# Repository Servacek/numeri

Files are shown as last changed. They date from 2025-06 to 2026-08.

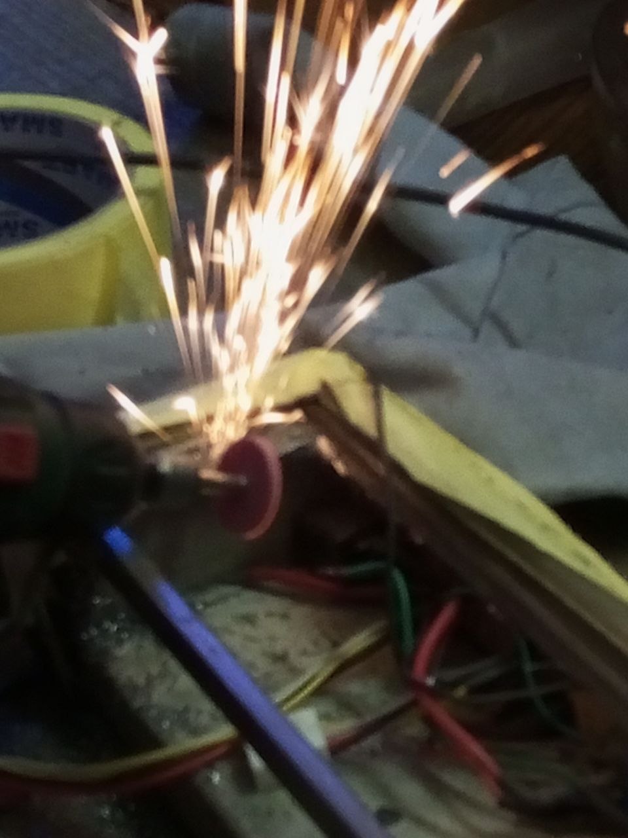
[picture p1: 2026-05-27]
docs/pictures/dokumentacne_foto/photo_2026-05-26_11-01-02.jpg

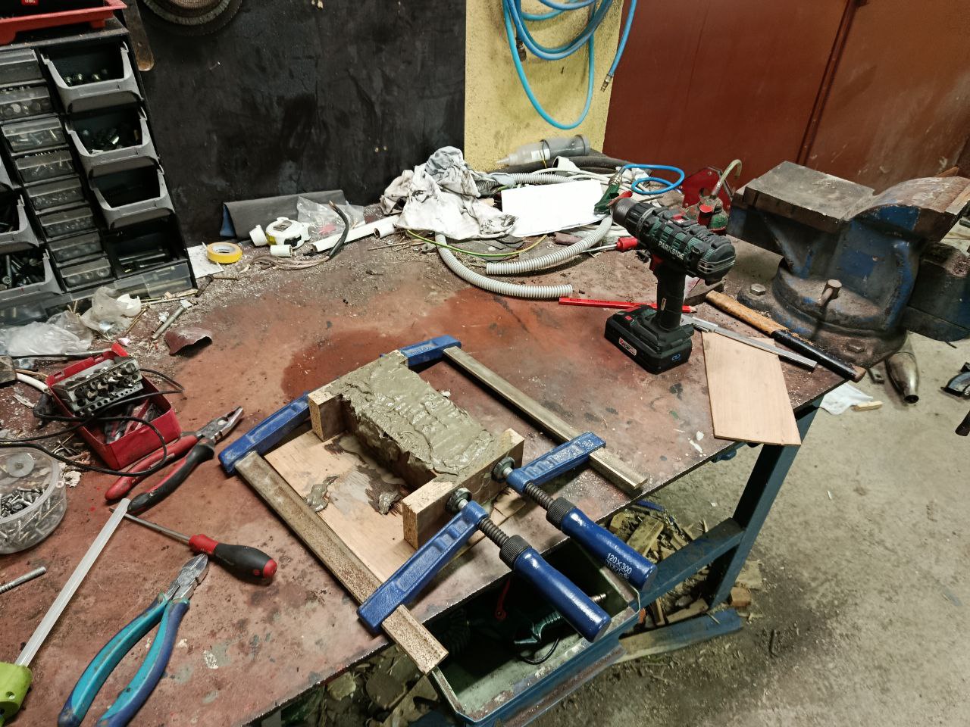
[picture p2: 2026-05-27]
docs/pictures/dokumentacne_foto/photo_2026-05-26_11-04-23.jpg

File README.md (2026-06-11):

# Numitronové Hodiny - Numeri

Digitálne hodiny využívajúce na zobrazovanie času staré sovietske numitrony IV-9. Podporujú tiež pripojenie rádiového modulu DCF77 pre automatické nastavovanie času podľa atomových hodín z Mainflingenu.

https://github.com/user-attachments/assets/5947127a-6d7e-4e79-9d8d-92cfa04d009d

## DCF77 Anténa



Vlastná 140 mm anténa sa zdá byť najefektívnejšie a cenovo najdostupnejšie riešenie. Čim väčšia feritová tyč, tým lepšie.

## Schéma zapojeniaa návrh plošného spoja




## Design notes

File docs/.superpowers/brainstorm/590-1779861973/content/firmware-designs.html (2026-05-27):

# Superpowers Brainstorming

Connected

Three design directions for the firmware features section. Click the one you like best.

Option A — Description list

Description List Clean · technical · readable

Firmvér pre Numeri hodiny beží na mikrokontroléri ATmega328P (16 MHz). Napísaný v C++ s inline AVR asemblerom — bez operačného systému, bez dynamickej alokácie.

DS3231 RTC Presný čas s teplotne kompenzovaným oscilátorom, uchovaný aj po výpadku napájania.

DCF77 sync Automatická synchronizácia s európskym rádiovým časovým signálom.

Auto-jas & noc LDR senzor pre stmievanie; konfigurovateľný nočný režim vypne displej.

Časovače Až 4 hodinové udalosti — nočný režim, DCF sync alebo zmena jasu.

Crossfade Plynulé ISR-riadené prechody číslic pri každej zmene hodnoty.

Teplota & log Zobrazenie teploty z AVR senzora; sériový debug monitor.

↓ Stiahnuť firmvér

⬡ Celý repozitár

Ako skompilovať a nahrať

Option B — Inline table

Compact Table Dense · scannable · data-forward

Firmvér pre Numeri hodiny beží na mikrokontroléri ATmega328P (16 MHz). Napísaný v C++ s inline AVR asemblerom — bez operačného systému, bez dynamickej alokácie.

DS3231 RTC | Presný čas s TXCO, uchovaný po výpadku napájania.
DCF77 | Automatická synchronizácia s rádiovým časovým signálom.
Auto-jas / noc | LDR pre automatické stmievanie; nočný režim vypne displej.
Časovače ×4 | Hodinové udalosti — nočný režim, DCF sync, zmena jasu.
Crossfade | ISR-riadené PWM prechody číslic.
Teplota / log | AVR teplomer; sériový monitor s úrovňami logu.

↓ Stiahnuť firmvér

⬡ Celý repozitár

Ako skompilovať a nahrať

Option C — Tags only, no descriptions

Feature chips Minimal · action-first

Firmvér pre Numeri hodiny beží na mikrokontroléri ATmega328P (16 MHz). Napísaný v C++ s inline AVR asemblerom — bez operačného systému, bez dynamickej alokácie. Podporuje DS3231 RTC, DCF77 synchronizáciu, automatický jas, nočný režim, crossfade animácie a sériový monitor.

DS3231 RTC DCF77 Auto-jas Nočný režim Crossfade Teplomer Serial monitor

↓ Stiahnuť firmvér

⬡ Celý repozitár

Ako skompilovať a nahrať

Click a design to select it, then let me know in the terminal

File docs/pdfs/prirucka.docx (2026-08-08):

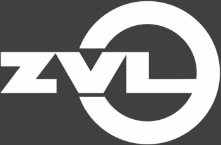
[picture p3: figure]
Úvod - ZVL SLOVAKIA

NUMERI 50

Digitálne hodiny

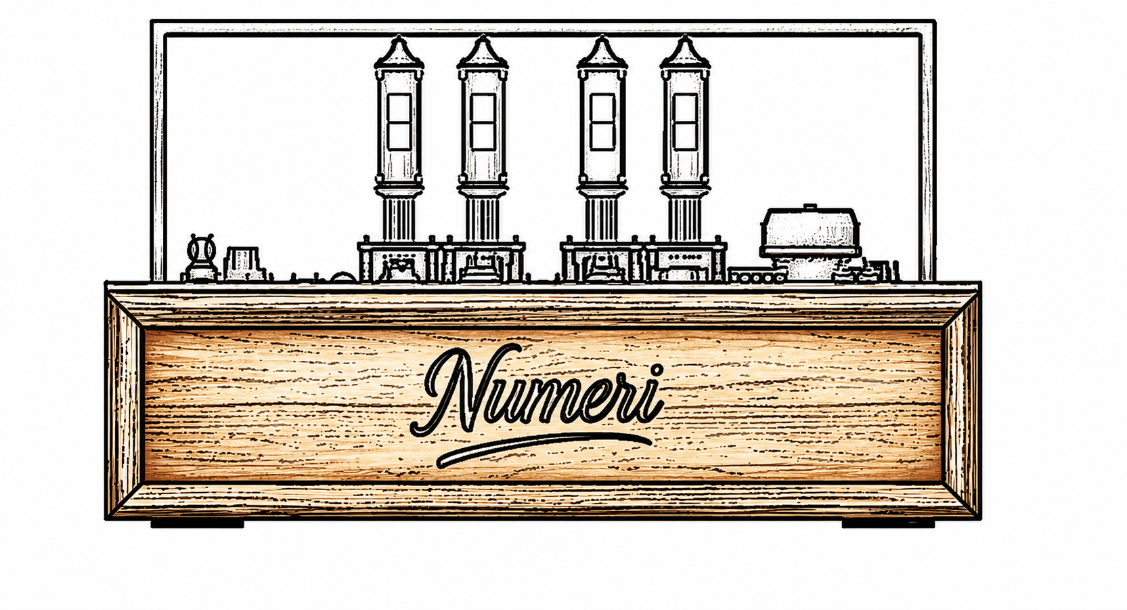
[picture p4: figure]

Návod na obsluhu

Obsah

# Digitálne hodiny Numeri 50

## Úvod

Numeri 50 sú rádiovo nastaviteľné digitálne hodiny, ktoré na zobrazovanie času používajú sovietske numitrony IV-9.

## História numitronov IV-9

V druhej polovici 60. a začiatkom 70. rokov potrebovala sovietska prístrojová a špeciálna technika kontrastný, odolný a jednoducho ovládateľný číslicový displej. LED-ky sa zatiaľ len vyvíjali a boli príliš drahé na praktické použitie.

Oproti známym a rozšíreným digitronom, v ktorých svietil dútnavý výboj v neónovej banke so studenou katódou, numitrony fungovali v podstate na princípe klasickej žiarovky. Išlo teda o akúsi 7-segmentovku, kde jednotlivé segmenty boli tvorené nízkopríkonovými wolfrámovými vláknami. Ich zapojenie bolo teda veľmi jednoduché a vyžadovalo len malé napätie, ktoré zvládali aj vtedajšie polovodiče.

IV-9 sa montoval vo viacerých lampových závodoch v rámci rozsiahlej sovietskej siete elektrovákuových podnikov. V praxi sa IV-9 objavoval v hodinách, kalkulačkách, meradlách a v špeciálnej aparatúre.

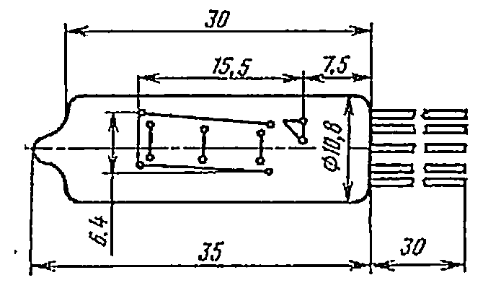
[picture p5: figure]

Obr. 1 Kótovaný technický nákres numitronu IV-9 z pôvodných sovietskych dokumentov.

Technické údaje o použitých numitronoch IV-9:
Model: IV-9 (ИВ-9)
Rok výroby: 1984
Menovité napätie: 3,15 V
Menovitý prúd: ~20–22 mA na segment
Jas: ≥ 2000 cd/m²
Životnosť: minimálne 10 000 hodín

## Ovládací panel

1 | Tlačidlo zmeny hodnoty na pozícii kurzora. ()
2 | Vypínač hodín (hore zapnuté, dole vypnuté).
3 | Napájací USB-C konektor (vstup 5 V a aspoň 1 A).
4 | Konektor na pripájanie DCF77 prijímača (typ GX-12).
5 | Indikačná RGB luminiscenčná dióda (LED).
6 | Tlačidlo posunu kurzora. ()

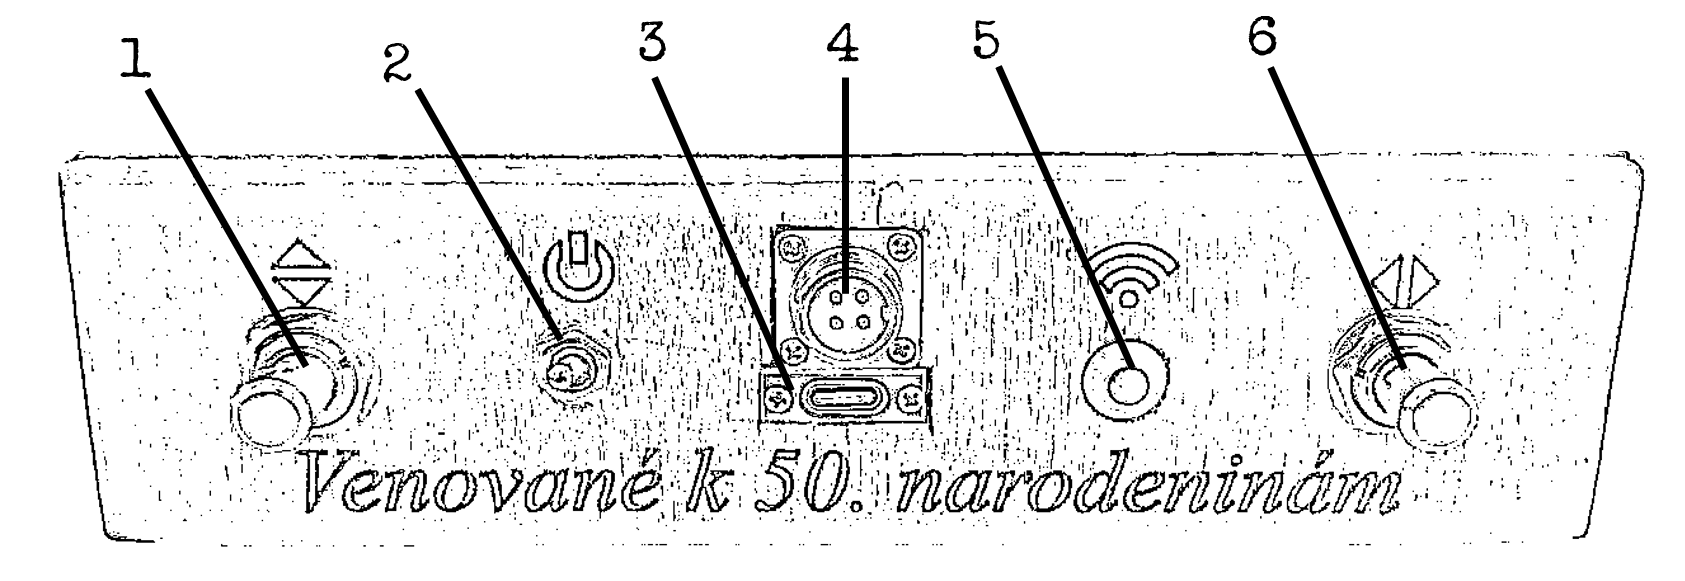
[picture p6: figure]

Obr. 2. Ovládací panel hodín na zadnej strane podstavca.

## Nastavovanie hodín

Na krajoch ovládacieho panela sa nachádzajú dve tlačidlá označené ikonkami a , ktoré umožňujú nastavovanie hodín. Pre vstup do nastavovacieho režimu držte obe tlačidlá stlačené dovtedy, kým sa nezobrazí kurzor (malá šípka vpravo dole na jednom z numitronov, viď Obr. 3). Ukončenie nastavovacieho režimu funguje rovnako — dlhým stlačením oboch tlačidiel, kým kurzor úplne nezmizne.

V nastavovacom režime každý numitron zodpovedá jednému konkrétnemu nastaveniu. Číslo zobrazené na danom numitrone určuje aktuálnu hodnotu tohto nastavenia. Pomocou tlačidla sa presúva kurzor medzi jednotlivými numitronmi a tlačidlom sa mení hodnota vybraného nastavenia.

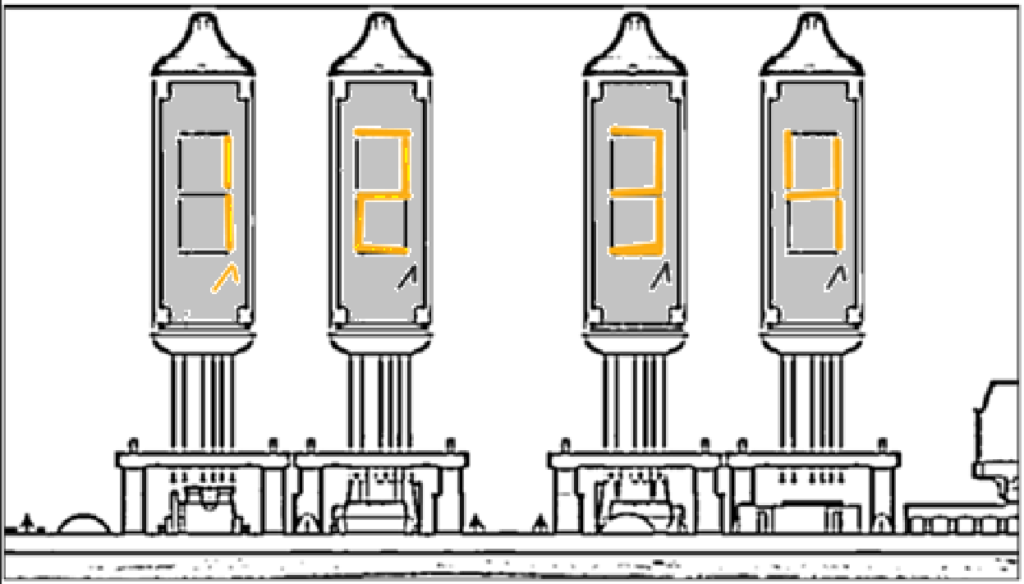
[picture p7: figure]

Obr. 3 Detailný pohľad na numitronový displej v nastavovacom režime (viditeľný kurzor na prvom numitrone). Každý z numitronov displeja zobrazuje svoje poradové číslo pre demonštračné účely.

Kurzor

## Stránky nastavení

Keďže počet nastavení je pomerne veľký, numitronový displej ich nedokáže zobraziť všetky naraz, preto sú rozdelené do tzv. stránok nastavení.

Stránka je jednoducho štvorica nastavení zobrazená naraz (každé nastavenie zobrazuje jeden numitron). Pre každú zo stránok sa nižšie nachádza tabuľka ktorá danú stránku a jej nastavenia popisuje týmito tromi stĺpcami:

1. prvý stĺpec obsahuje poradové čísla numitronov (číslované spredu zľava, viď Obr. 3),
2. druhý stĺpec uvádza rozsah hodnôt, ktoré dané nastavenie môže nadobudnúť, pričom hodnota v zátvorke predstavuje predvolenú hodnotu,
3. tretí stĺpec poskytuje stručný popis príslušného nastavenia a jeho možných hodnôt.

Medzi stránkami je možné prechádzať krátkym stlačením oboch krajných tlačidiel. Pri prechode na novú stránku sa zmeny vykonané na predchádzajúcej stránke uložia.

Poradové číslo numitronu | Rozsah hodnôt | Stručný popis nastavenia prípadne jeho možných hodnôt.

STRANA 1 – Nastavenia času
1. | (0)-2 | Cifra desiatok hodín.
2. | (0)-9 | Cifra jednotiek hodín.
3. | (0)-5 | Cifra desiatok minút.
4. | (0)-9 | Cifra jednotiek minút.

STRANA 2 – Všeobecné nastavenia
1. | 0, (1) | 0 – Manuálny jas, 1 – Automatický jas,
2. | 0-8 (5) | Úroveň jasu indikačnej LED: 0 – vypnutá, 8 – maximálny jas,
3. | (0), 1 | Prúdový senzor displeja: 0 – vypnutý (bez softvérovej ochrany) 1 – zapnutý (ochrana pred nadprúdom a podprúdom) Poznámka: Predvolene vypnutý pre prípad vážnej chyby senzora. Výrobné nastavenia je vždy možné obnoviť dlhým stlačením tlačidla RESET (viď strana 12).
4. | 0, (1) | Vypínanie prijímača DCF77: 0 – DCF77 prijímač vypnutý, 1 – DCF77 prijímač zapnutý,

STRANA 3 – Časovače
1. | (0)-4 | Identifikačné číslo (ID) časovača.
2. | (0)-3 | Akcia časovača. 0 – žiadna akcia, 1 – zapnutie nočného režimu (viď strana 13), 2 – vypnutie nočného režimu, 3 – vykonanie 60 minútového pokusu o synchronizáciu času pomocou DCF77 prijímača (viď strana 15),
3. | (0)-2 | Cifra desiatok hodín časovača.
4. | (0)-9 | Cifra jednotiek hodín časovača.

Poznámka: časovače slúžia na automatické spúšťanie určitých akcií (viď zoznam vyššie) v nastavenom čase. Ak je viac časovačov nastavených na rovnakú hodinu, spustia sa podľa poradia ich identifikačných čísel (ID) (t. j. časovač s najmenším číslom prvý, po ňom časovač s druhým najmenším číslom atď...).

Číslo numitronu | Rozsah hodnôt | Stručný popis nastavenia

STRANA 4 – Dátum
1. | (0)-3 | Cifry aktuálneho dňa, napr. 20.
2. | 0-9 (1)
3. | (0)-1 | Cifry aktuálneho mesiaca, napr. 12.
4. | 0-9 (1)

STRANA 5 – Rok
1. | (O)-9 | Cifry aktuálneho roku po poradí. Hodiny tento údaj používajú na určovanie priestupných rokov.
2. | (0)-9
3. | (O)-9
4. | (O)-9

Poznámka: Hodnota v zátvorke je predvolená (výrobné nastavenie).

Pre ukončenie nastavovacieho režimu držte stlačené obe krajné tlačidlá až kým nezmizne kurzor. Prípadne sa nastavovací režim vypne automaticky po piatich minútach neaktivity a to bez uloženia zmien na poslednej upravovanej stránke nastavení.

## Nastavovanie jasu displeja

Mimo nastavovacieho režimu slúžia krajné tlačidlá aj na nastavovanie jasu numitronového displeja. Táto funkcia je dostupná len vtedy, keď je v nastaveniach hodín vypnuté automatické riadenie jasu.

— zvýši jas displeja o jednu úroveň
— zníži jas displeja o jednu úroveň

## Zobrazovanie dátumu a teploty

Krátkym stlačením oboch tlačidiel sa zobrazí teplota okolia, ďalším stlačením dátum — oba údaje len na pár sekúnd, po ktorých sa hodiny vrátia k zobrazeniu času.

## Základné komponenty hodín

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
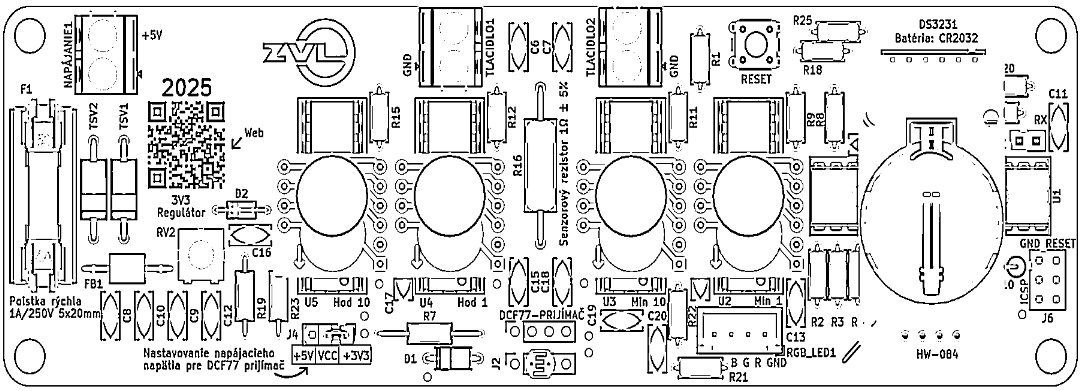
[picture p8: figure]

Obr. 4 Pohľad zhora na dosku plošného spoja a jej komponenty.

## 1. Poistka

Ide o hardvérovú ochranu pred nadprúdom. Poistka je dimenzovaná tak, aby sa vypálila len pri závažnej chybe v elektronike hodín. Teda pri vypálení, odporúčame problém riešiť servisne (viď strana 18).

## 2. Napájanie

Hodiny sa napájajú zo zdroja s výstupom 5 V schopným dlhodobého dodávania výkonu o veľkosti aspoň 5 W.

## 3. QR-kód s odkazom na web

Na doske plošného spoja sa zhora z pohľadovej časti nachádza QR-kód, ktorý obsahuje odkaz na stránku hodín, na ktorej nájdete elektronickú podobu tohto návodu na obsluhu, 3D model a schému hodín, fotografie z procesu návrhu a výroby ako aj kompletný stiahnuteľný firmvér. Odkaz stránky: https://servacek.github.io/numeri/

## 4. Trimmer nastavujúci úroveň napätia DCF77 prijímača

Doska hodín disponuje vlastným napäťovým regulátorom so Zenerovou diódou, ktorý vytvára nastaviteľné napätie (1,1 – 3,6 V) pre DCF77 prijímač — rôzne typy prijímačov totiž vyžadujú rôzne napájacie napätie.

Výstupné napätie regulátora sa nastavuje pomocou trimmera. S trimmerom manipulujte len v nevyhnutných prípadoch (napr. pri výmene prijímača) — nesprávne nastavenie môže viesť k trvalému poškodeniu prijímača.

## 5. Prepojka nastavujúca napäťový zdroj DCF77 prijímača

V prípade potreby sa dá regulátor (4) prepojkou obísť úplne a napájať prijímač priamo zo zdroja hodín (5 V). Pozor — priame napájanie môže poškodiť prijímač s nižším napájacím napätím ako 5 V.

## 6. Svetelný senzor pre automatické prispôsobenie jasu

Hodiny si dokážu regulovať jas displeja na základe okolitého svetla (napr. cez deň je žiaduce, aby displej svietil silnejšie ako v noci). Pri zapnutom automatickom jase nejde nastavovať jas manuálne. Túto funkciu je možné vypnúť v nastaveniach (viď strana 8).

## 7. Senzor prúdového odberu displeja

V rámci ochrany hodín aj numitronov používame priemyselný prúdový senzor s presnosťou 0,5%. Tento senzor umožňuje mikrokontroléru rozpoznať chyby displeja, napríklad vypálené vlákno alebo skrat, a potom displej hodín bezpečne vypnúť.

## 8. Tlačidlo RESET

Krátkym stlačením tlačidla sa hodiny reštartujú. Ak tlačidlo podržíte počas celého spúšťania zariadenia (indikovaného žltou farbou indikačnej LED, viď stranu 16), obnovia sa výrobné nastavenia.

## 9. Mikrokontrolér

Hodiny sú riadené čipom ATmega328 s predinštalovaným firmvérom, ktorý je možné v prípade potreby preinštalovať pomocou ICSP zbernice osadenej na doske hodín.

Súčasťou čipu je aj 1 kB EEPROM pamäť, ktorá uchováva nastavenia aj po odpojení hodín z elektrickej siete. Životnosť každej z jej pamäťových buniek je 100 000 zápisov. Ak sa nastavenia neukladajú, jedinou opravou je výmena celého čipu ATmega328 a opätovné napálenie firmvéru dostupného na stránke hodín.

## 10. Záložná batéria

Zaisťuje zachovanie času aj pri odpojení hodín z elektrickej siete. Pri bežných podmienkach by mala vydržať približne 5 rokov. Ak si hodiny nezachovávajú správny čas po vypojení zo siete, batériu je treba vymeniť za mincovú batériu CR2032 podobnej kvality.

## 11. UART zbernica

Používa sa pri ladení firmvéru hodín, pretože umožňuje odosielať stavové výpisy (logy) z hodín do počítača.

## 12. ICSP zbernica

Umožňuje nahrávanie firmvéru do mikrokontroléra hodín pomocou špeciálnych USB zariadení (tzv. ICSP programátorov). Pri použití vhodného softvéru je možné na programovanie využiť aj vývojovú dosku Arduino. Ak chcete dosku hodín napájať priamo z ICSP zbernice, je potrebné najprv prepnúť vypínač hodín (viď obr. 2) do vypnutej polohy, aby sa predišlo súbehu viacerých zdrojov napájania.

## Nočný režim

Režim, v ktorom je displej vypnutý, zatiaľ čo hodiny zostávajú zapnuté. Stlačením ľubovoľného tlačidla panelu sa displej na niekoľko sekúnd opäť zapne. Pri vstupe do nastavení hodín sa nočný režim vypne úplne.

## Úložný priestor

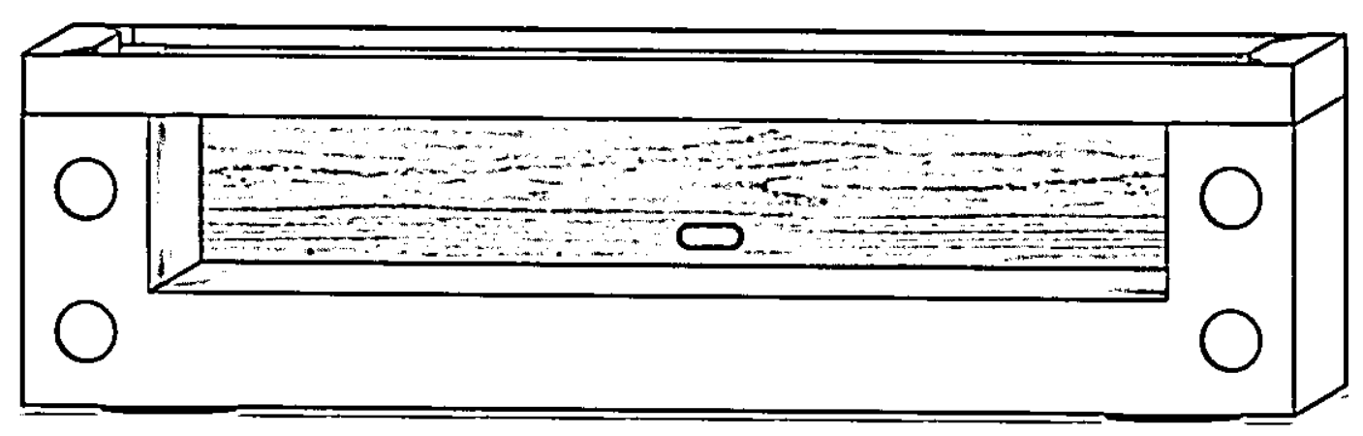
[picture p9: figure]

Obr. 5 Podstavec hodín s odkrytým predným krytom, uchyteným magnetmi, ktorý odhaľuje úložný priestor.

Súčasťou podstavca hodín je aj úložný priestor na náhradné diely a nástroje na základný servis.

Obsahuje:

- náhradný numitron osadený na pätici
- náhradnú mincovú batériu CR2032
- schému zapojenia hodín vo formáte A2

# Prijímač DCF77

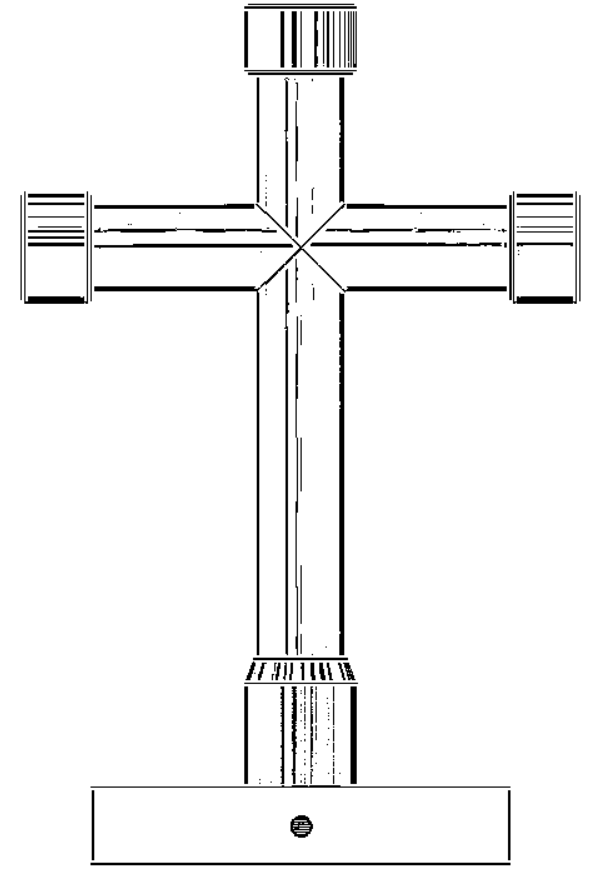
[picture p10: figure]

Obr. 6 Prijímač rádiového signálu DCF77 na podstavci

K hodinám sa dodáva aj rádiový prijímač v tvare kríža, v ktorom je umiestnená 140-milimetrová feritová anténa vlastnej výroby, odladená tak, aby rezonovala pri frekvencii 77,5 kHz na ktorej vysielajú atómové hodiny z Mainflingenu (Nemecko) svoj časový signál. Tento signál používajú hodiny k automatickému nastaveniu času a prechodu zo zimného času na letný a naopak.

## Orientácia prijímača

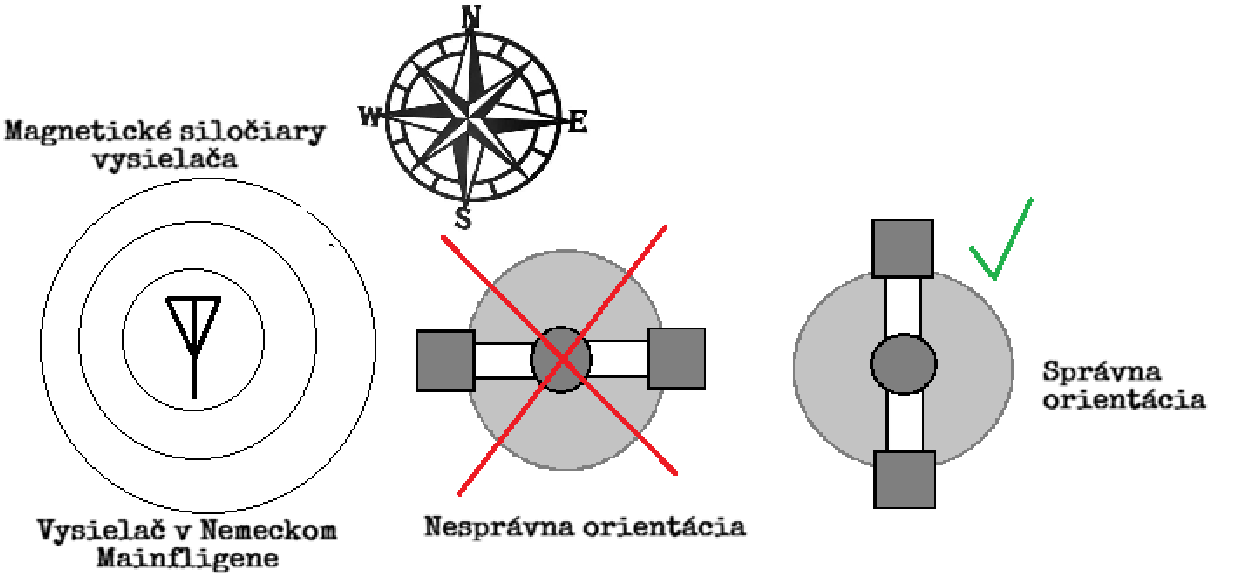
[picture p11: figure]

Obr. 7 Správna a nesprávna orientácia prijímača voči vysielaču.

Keďže feritové antény sú z povahy závislé od orientácie, odporúčame prijímač otočiť tak, aby ramená jeho kríža smerovali na sever a juh (ako je vidieť na Obr. 7). Ak je orientácia správna a signál dostatočne kvalitný, indikačná LED by mala blikať v pravidelných sekundových intervaloch oranžovou farbou.

## Automatické nastavenie hodín

Hodiny sa pokúsia o synchronizáciu ihneď po zapnutí alebo v čase nastavenom v časovači. Ak sa synchronizácia nepodarí do 60 minút, pokusy sa ukončia a obnovia sa až pri ďalšom podnete.

## Stavy indikačnej LED

Indikačná RGB LED na zadnom paneli slúži na informovanie používateľa o stave hodín bez narušenia zobrazenia času na numitronovom displeji. Rôzne farby a režimy blikania signalizujú konkrétne stavy zariadenia.

Stav indikačnej LED | Význam
Oranžové bliknutie raz za sekundu | Synchronizácia času práve prebieha a signál je kvalitný.
Chaotické oranžové blikanie | Synchronizácia času práve prebieha ale signál je nekvalitný alebo zarušený.
Stála žltá farba | Hodiny sú v procese načítavania a inicializácie a nie je možné ešte s nimi interagovať.
Stála zelená farba | Čas bol naposledy úspešne synchronizovaný.
Stála červená farba | Posledný pokus o synchronizovanie času bol neúspešný.
Stála modrá farba | Nahrávanie nového programu do mikrokontroléra hodín.
Intenzívne pravidelné blikanie červenou farbou | Prúdový senzor displeja zaznamenal nadprúd (napr. skrat).
Intenzívne pravidelné blikanie modrou farbou | Prúdový senzor displeja zaznamenal podprúd (napr. vypálený alebo zle pripevnený numitron).
Trojité bliknutie bielou farbou | Hodiny boli obnovené na výrobné (predvolené) nastavenia pomocou dlhého stlačenia tlačidla RESET (viď Obr. 4).

V prípade potreby je možné v nastaveniach hodín upraviť jas tejto indikačnej LED, aby bola menej rušivá, prípadne ju kompletne vypnúť (nastavením jasu na 0), viď strana 8.

## Numitronový displej a jeho životnosť

Numitrony displeja sú pri prevádzke napájané regulovaným spínaným napätím s maximálnou efektívnou hodnotou (dosiahnutou pri maximálnom jase) pohybujúcou sa okolo 1,5 V až 2 V.

Ide o napätie, ktoré je výrazne nižšie ako maximálne dovolené napätie uvádzané v oficiálnych dokumentoch (4,5 V) ako aj nominálne napätie (3,15 V), pričom displej stále ostáva dobre čitateľný.

Štúdie ukazujú, že životnosť volfrámových vlákien rastie exponenciálne so znižujúcim sa napätím, zatiaľ čo jas klesá len lineárne (viď obr. 8). Vďaka prevádzke pri zníženom napätí je možné predĺžiť životnosť displeja z pôvodných približne 10 000 hodín až na viac ako 500 000 hodín. Zmeny napätia vlákien sú realizované plynule, aby sa predišlo nadprúdom pri zapnutí, ktoré vznikajú v dôsledku nízkeho odporu studených vlákien.

Pre dosiahnutie čo najdlhšej životnosti numitronov odporúčame nastaviť čo najnižší jas a použiť dva časovače – jeden na večerné vypnutie displeja a druhý na jeho zapnutie nad ránom (viď strana 8).

Zmeny v %

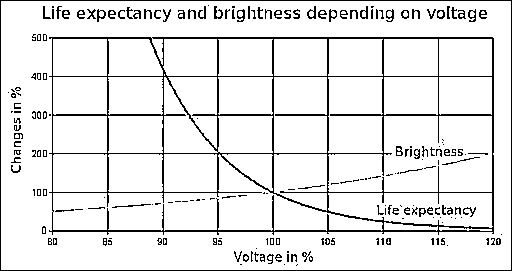
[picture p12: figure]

Obr. 8 Závislosť životnosti vlákien na napájacom napätí

Jasnosť

% z nominálného napätia

Životnosť

## Riešenie problémov

Problém | Riešenie
Hodiny si neudržujú správny čas po vypnutí. | Mincová batéria (Obr. 4) je vybitá.
Hodiny sa oneskorujú alebo nefunguje automatická synchronizácia času. | Uistite sa, že orientácia prijímača je správna (Obr. 7) a prijímač je pevne pripojený. Následne hodiny reštartujte pre zahájenie opätovnej synchronizácie. Indikačná LED by mala počas synchronizácie blikať v pravidelných sekundových intervaloch oranžovou.
Niektoré vlákna nesvietia. | Reštartujte hodiny. Pri štarte by sa mali rozsvietiť všetky vlákna na všetkých numitronoch. Numitrony, u ktorých sa nerozsvietili všetky vlákna je potrebné vymeniť za nové. Kontaktujte servis.
Hodiny sa nedajú zapnúť. | Uistite sa, že hodiny sú napájané z vhodného zdroja a hlavná poistka hodín nie je vypálená (Obr. 4).
Displej hodín sa chvíľu po zapnutí vypne a pravidelne sa rozbliká LED-ka na červeno alebo modro. | Prúdový senzor displeja zrejme deteguje chybu (viď tabuľku stavov indikačnej LED). Ideálne kontaktujte servis, keďže sa môže jednať o vážnu chybu v hardvéri. Alternatívne, ak viete, čo robíte, obnovte výrobné nastavenia tlačidlom RESET (viď Obr. 4), čo senzor vypne.

## Servis

V prípade poruchy vyžadujúcej servis volajte na jedno z dostupných tel. čísiel zo zoznamu nižšie alebo navštívte našu pobočku v Korni.

# Autori projektu

Vedúci projektu: | | Filip Mitka
Vedúci výroby: | | Kristián Perďoch
Vedúci výroby podstavcov: | | Bartolomej Mikula
Biblistika, výklad a export: | | Jozef Hroš

Na projekte ďalej spolupracovali

Kritici hardvéru: | Ing. Viliam Koprda, Ing. Dušan Dragúň
Drevo materiál: | Bohumil Jaroš
Laserové vypaľovanie: | Ing. Miroslav Hromada
Tlač návodu na obsluhu: | Zlatica Trúchla
Doska plošného spoja (DPS): | Bc. Jozef Kaduch
Chémia na leptanie DPS: | Ladislav Zimka
Elektromateriál: | MB Electronic Žilina, VP Centrum Litoměřice, PS Electronic Praha, J. Marek – portes.cz, Natália Mitková
Poskytovateľ numitronov: | Robert Ziedins, Lotyšsko

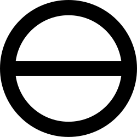
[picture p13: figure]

Prvé vydanie

2026

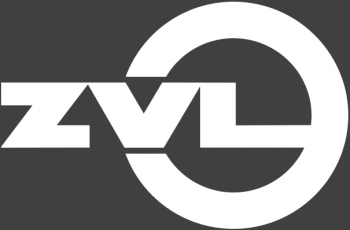
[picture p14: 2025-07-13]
assets/zvl-sign-white.png

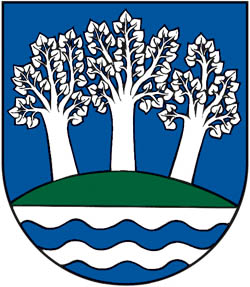
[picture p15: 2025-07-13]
assets/korna.jpg

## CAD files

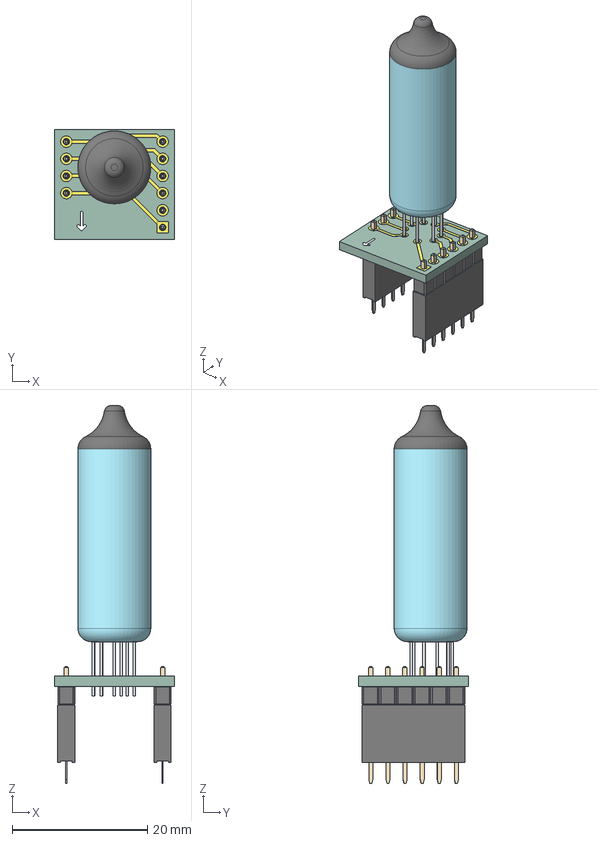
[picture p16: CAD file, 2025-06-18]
subprojects/external-iv9-socket/external-iv9-socket-full.step
17.8 x 16.3 x 56.0 mm
iv-9 v1
PinHeader_1x04_P2.54mm_Vertical
PinHeader_1x06_P2.54mm_Vertical
external-iv9-socket_copper
external-iv9-socket_silkscreen
external-iv9-socket_PCB
PinSocket_1x06_P2.54mm_Vertical
PinSocket_1x04_P2.54mm_Vertical

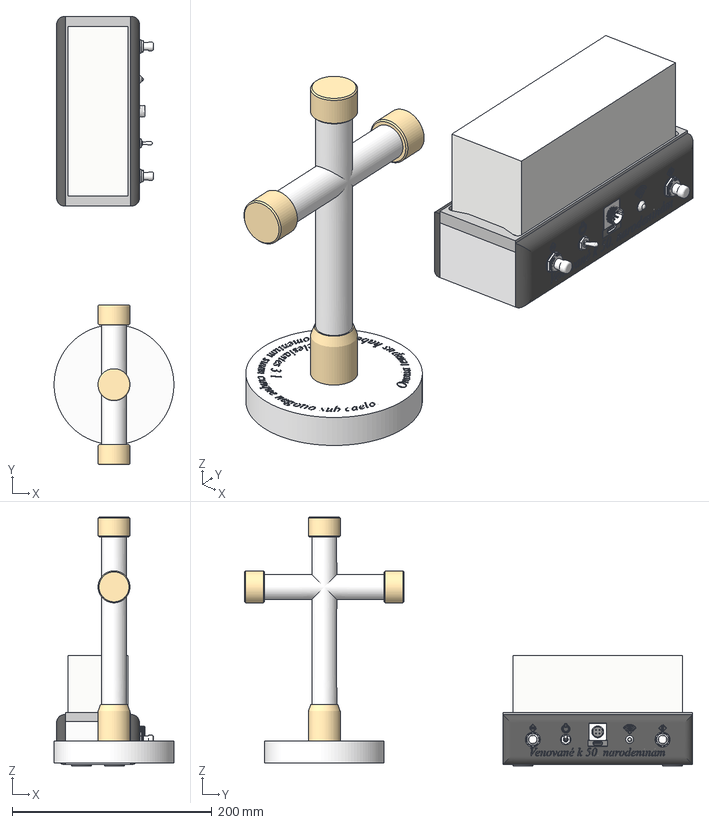
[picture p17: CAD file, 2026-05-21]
3dmodels/export/numitrónové hodiny.3mf
120.0 x 449.0 x 249.5 mm

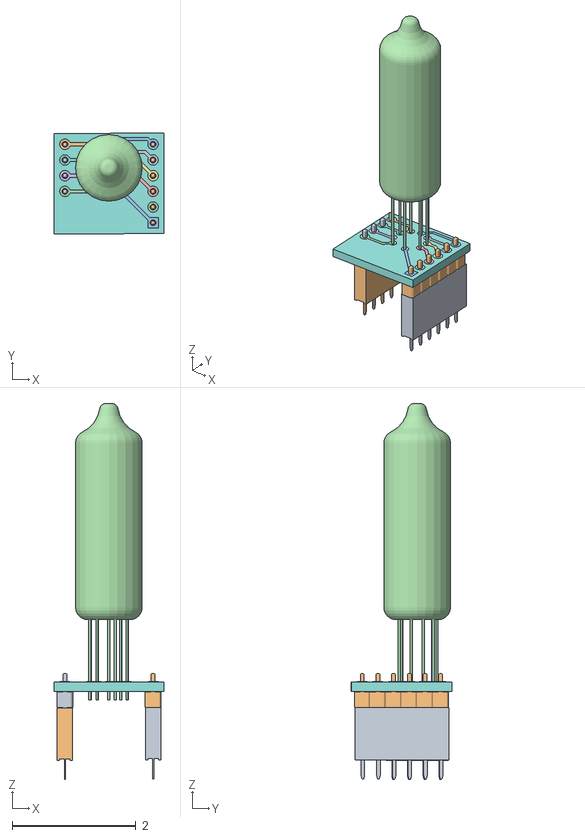
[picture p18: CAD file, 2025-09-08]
3dmodels/numitron-na-patici-s-priesvitnym-sklom v1.obj
1.78 x 1.63 x 6.09

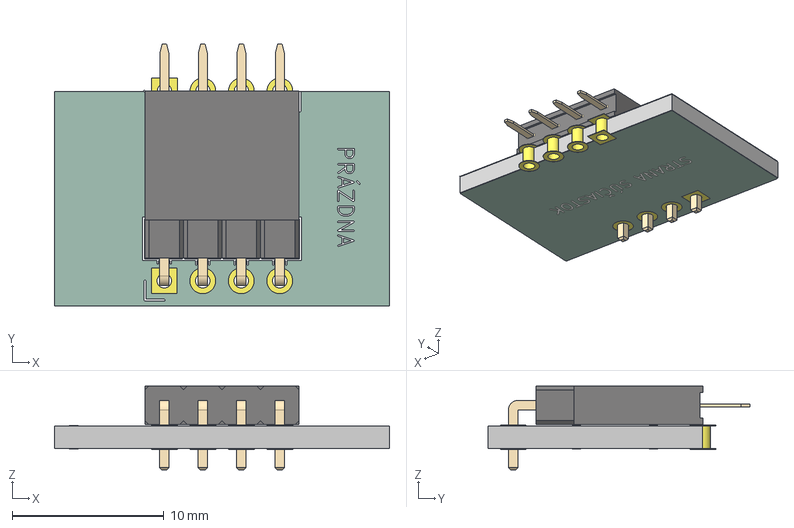
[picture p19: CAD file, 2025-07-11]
subprojects/dcf77-general-module/em2s-hkw-module.step
22.1 x 17.3 x 5.54 mm
PinSocket_1x04_P2.54mm_Vertical
PinHeader_1x04_P2.54mm_Horizontal
dcf77-general-module_copper
dcf77-general-module_silkscreen
dcf77-general-module_soldermask
dcf77-general-module_PCB

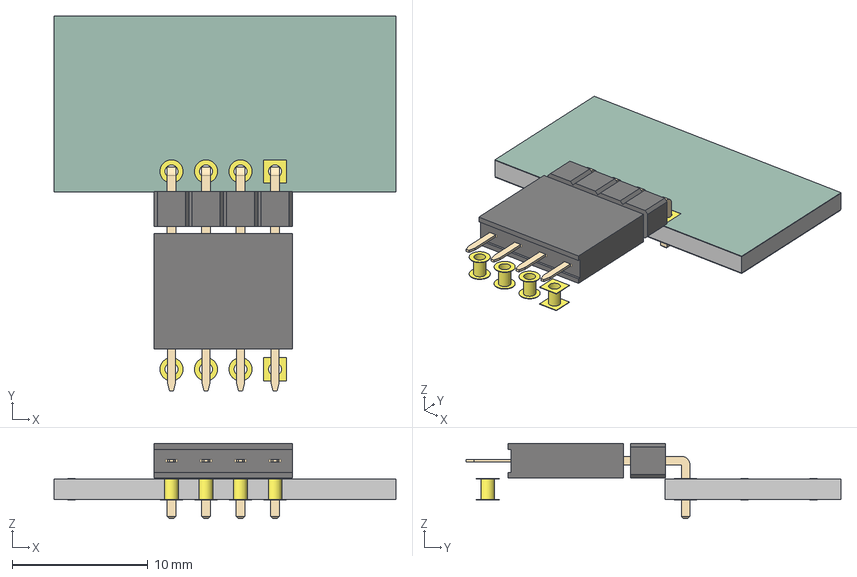
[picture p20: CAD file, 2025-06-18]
subprojects/em2s-hkw-module/em2s-hkw-module.step
25.1 x 27.6 x 5.54 mm
PinSocket_1x04_P2.54mm_Vertical
PinHeader_1x04_P2.54mm_Horizontal
em2s-hkw-module_copper
em2s-hkw-module_soldermask
em2s-hkw-module_PCB

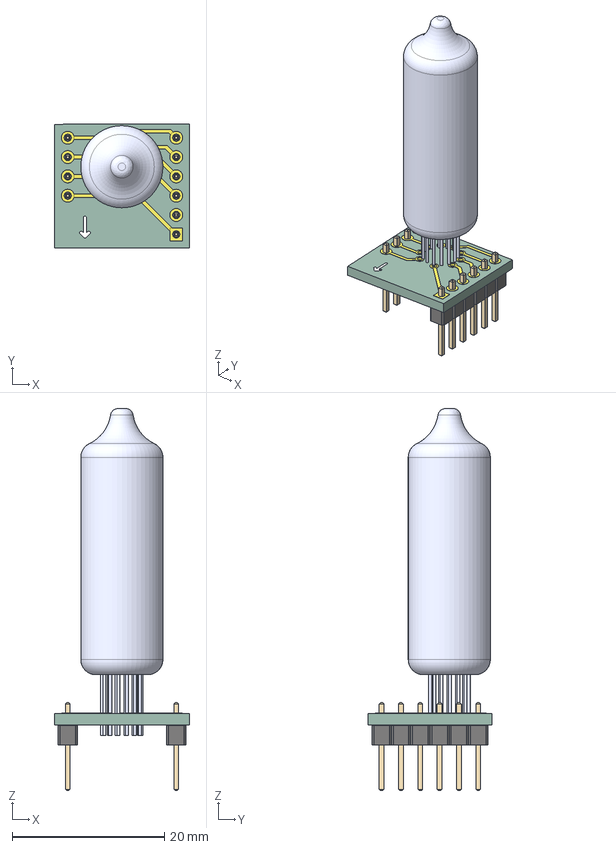
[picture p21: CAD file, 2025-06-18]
subprojects/external-iv9-socket/external-iv9-socket.step
17.8 x 16.3 x 50.2 mm
iv-9 v1
PinHeader_1x04_P2.54mm_Vertical
PinHeader_1x06_P2.54mm_Vertical
external-iv9-socket_copper
external-iv9-socket_silkscreen
external-iv9-socket_PCB

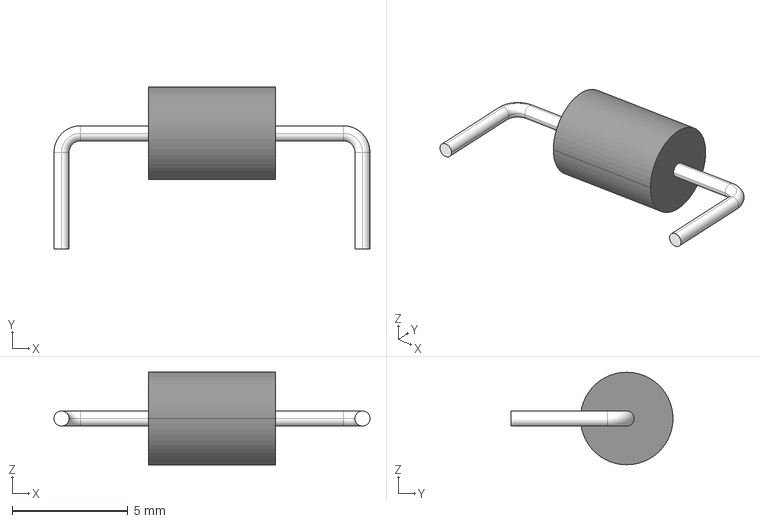
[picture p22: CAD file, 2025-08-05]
3dmodels/ferrite-h_p13_d4_l5-5.stp
13.6 x 7.00 x 4.00 mm

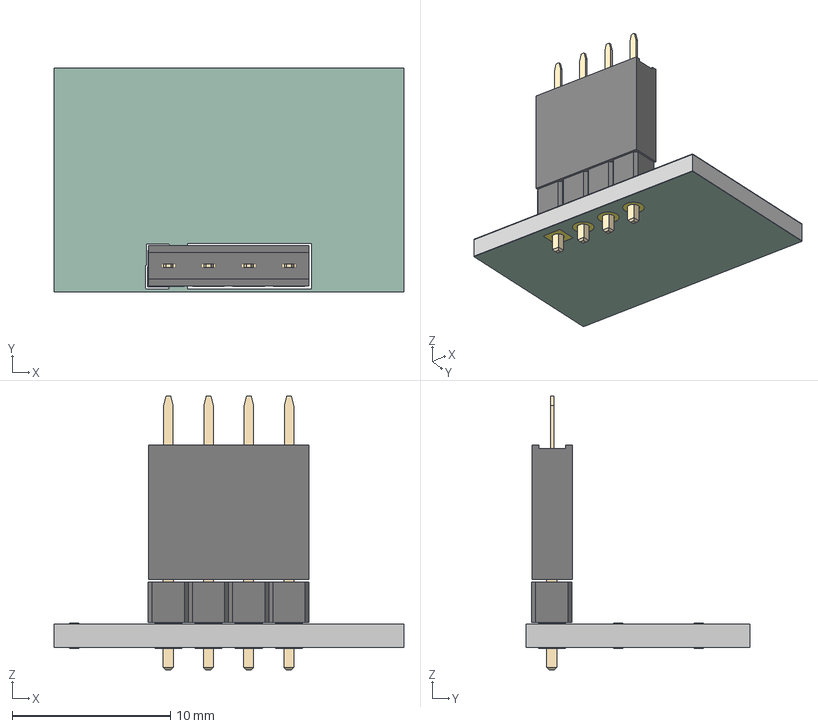
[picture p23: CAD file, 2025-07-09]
subprojects/dcf77-general-module/dcf77-general-module.step
22.1 x 14.2 x 17.3 mm
PinSocket_1x04_P2.54mm_Vertical
PinHeader_1x04_P2.54mm_Vertical
dcf77-general-module_copper
dcf77-general-module_silkscreen
dcf77-general-module_soldermask
dcf77-general-module_PCB

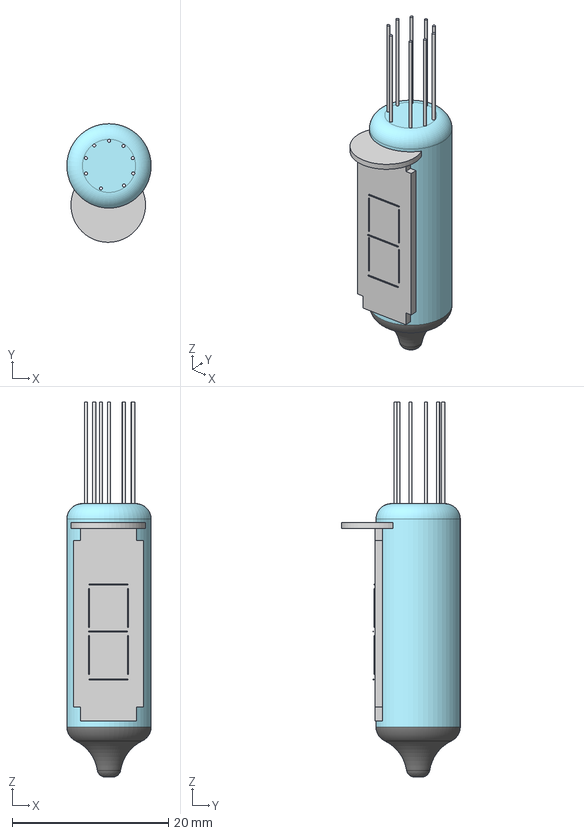
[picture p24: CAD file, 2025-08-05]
3dmodels/iv-9.step
10.8 x 15.2 x 48.0 mm
podstava
segment-6 x 7

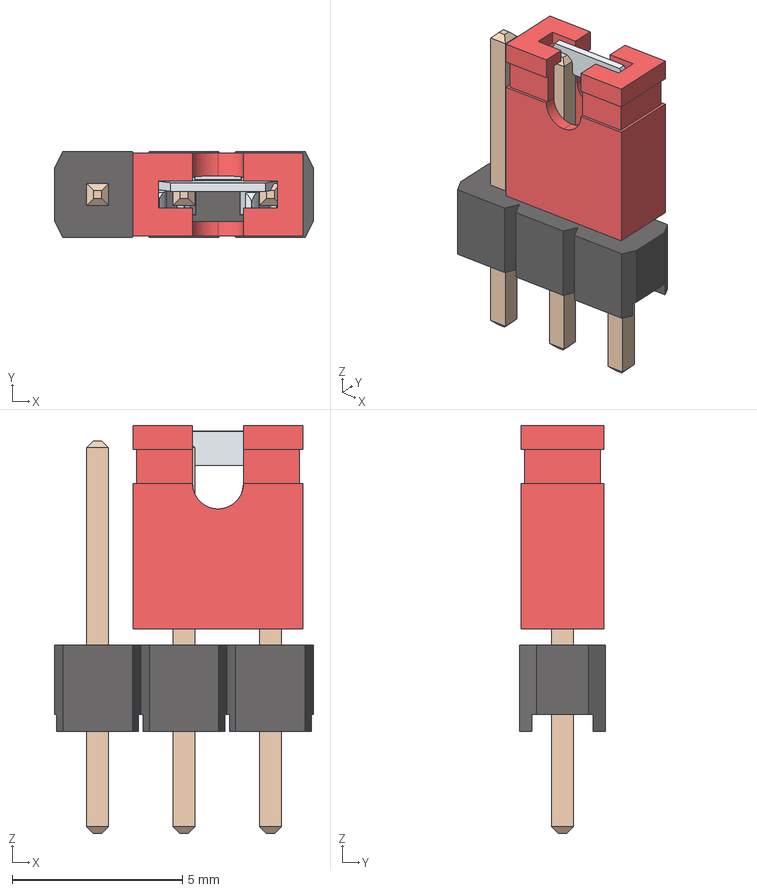
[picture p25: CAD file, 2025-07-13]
3dmodels/pin header 1x3 and jumper.step
7.62 x 2.54 x 12.0 mm

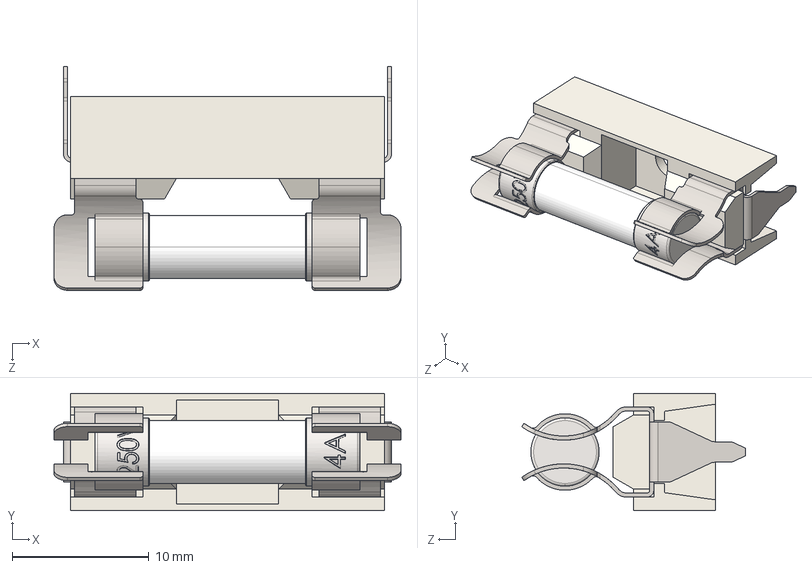
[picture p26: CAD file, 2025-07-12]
3dmodels/fuse-holder-5x20mm.STEP
25.4 x 8.60 x 16.4 mm

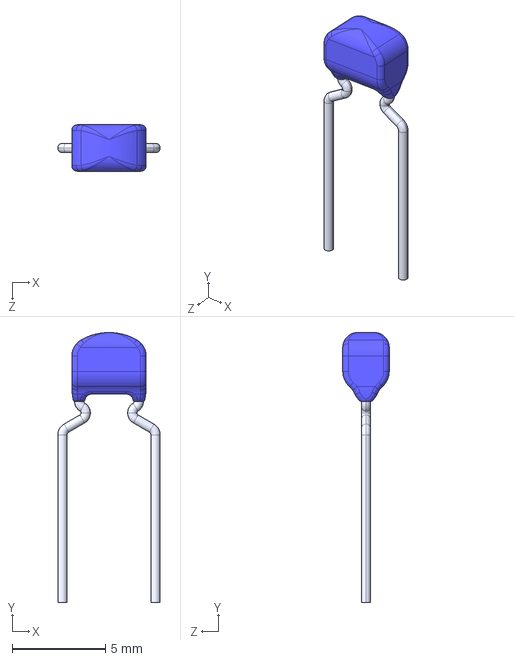
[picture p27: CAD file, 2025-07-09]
3dmodels/FG28X7R1E105KRT00.step
5.50 x 14.5 x 2.50 mm

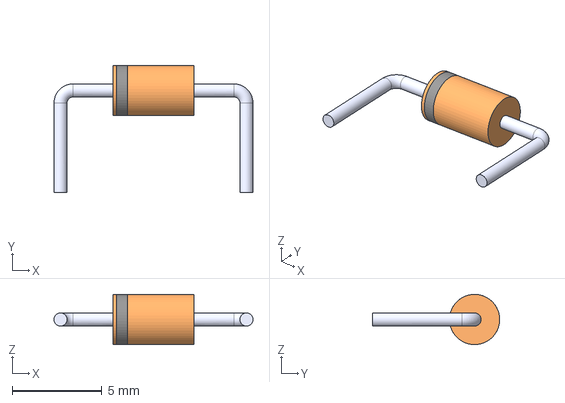
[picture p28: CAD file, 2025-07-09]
3dmodels/1N4728.step
11.1 x 7.10 x 2.80 mm

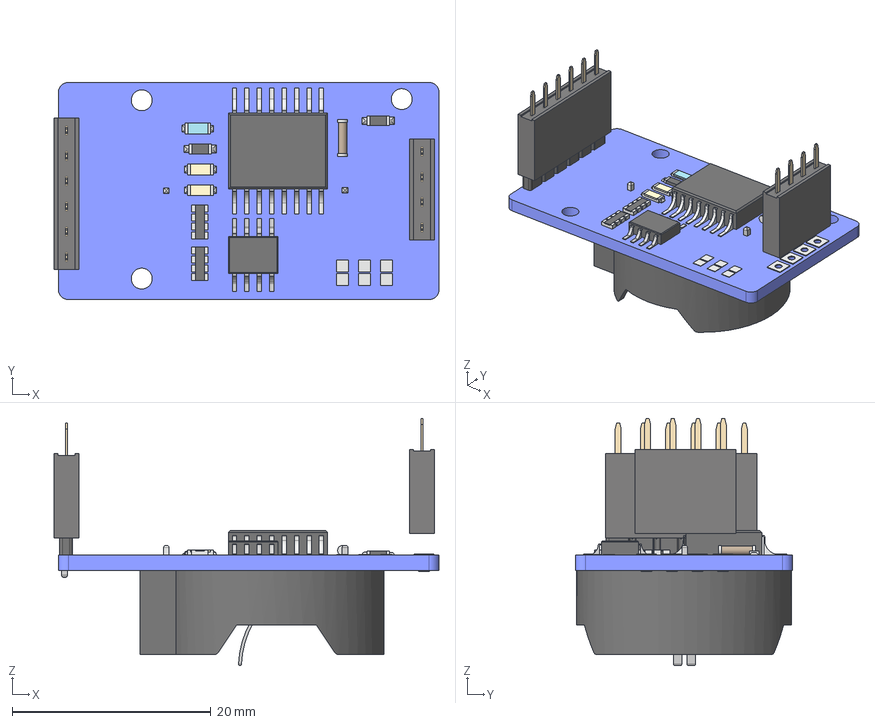
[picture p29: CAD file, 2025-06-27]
3dmodels/HW-84 v7 v2.step
38.7 x 21.9 x 24.9 mm
PinSocket_1x06_P2.54mm_Vertical
PinSocket_1x04_P2.54mm_Vertical

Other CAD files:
3dmodels/external-iv9-socket v13 v6.step
3dmodels/HW-84 v7.step
3dmodels/Battery Holder Top with CR2032.stp
3dmodels/external-iv9-socket-exposed.step
3dmodels/BH-642.STEP
3dmodels/export/stojan na anténu.f3d
3dmodels/external-iv9-socket v13.step
3dmodels/iv-9 v1.step
3dmodels/iv-9-no-transparency.f3d
3dmodels/iv-9-transparent.f3d
3dmodels/numitron-na-patici-s-priesvitnym-sklom.f3d
docs/models/clock-pcb.blend
docs/models/clock-with-antenna.blend
subprojects/external-iv9-socket/iv-9 v1.f3d
subprojects/external-iv9-socket/iv-9.f3d

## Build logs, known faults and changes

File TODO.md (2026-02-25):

# TODO:

# Hardware
- [x] Pojistka z vonku či zvnútra? (uvidí sa podľa návrhu) (najskôr zvnútra, zvonku je toho už dosť).
- [x] Kapacita na zdroji je príliš veľká pre USB-C špecifikáciu.
    - Pravdepodobne netreba tak veľkú kapacitu pretože numitronu nespúšťame všetky naraz.
- [x] ATtiny24 má príliš málo (2kB) pamäti flash pre utiahnutie programov na DCF77 demoduláciu.
    - Najväčší MCU so 14 pinmi z rady ATtiny je ATtiny84 (8kB) (https://www.vpcentrum.eu/attiny84a-pu-mikrokontroler-avr-flash-8kx8bit-eeprom-512b-sram-512b-dip14), čo je stále pomerne málo.
    - Prejdeme teda na ATmega328-PU ktorá má 32kB pamäte flash a 2kB pamäte RAM.
        - To nám umožní ľahšie vyvíjať softvér (bude kompatibilný s arduino UNO prototypom).
        - Dokáže utiahnuť bez modifikácií knižnicu od Uda Kleina na dekódovanie DCF77 signálu.
- [x] Ochrana pred prepätím na vstupe (vhodný transil) / pred skratom (vhodná rýchla poistka).
    - Transil použijeme [BZW06-5V8](https://www.gme.sk/v/1487314/stmicroelectronics-bzw06-5v8-unipolarny-transil),
      ktorý začne skratovať pri 5,8V čo by malo byť pod maximálnou hodnotou napätia pre IC s dosť veľkou rezervou.
    - Použijeme aspoň dva paralelne zapojené transily s vhodnou hodnotou, ideálne 5.5V pre čo najväčšiu prudovú výdrž.
- [x] Čo najkvalitnejšie Schottkyho diódy (s čo najmenším Uf) (1N5817)
    - K dispozícií sú pomerne veľké 1N5822, ktoré by mohli byť vhodnejšie než tie SR260.
    - Pre signálové linky použijeme, kde je dôležitá rýchlosť použijeme 1N4148.
    - Pre digitálne linky kde je dôležitý čo najmeší úbytok napätia aby bolo
      zkreslenie digitalnej hodnoty čo najmenšie použijeme 1N5819.
- ~~[-] Ochrana proti opačnej polarite MOSFET-om~~
    - Zbytočná pri USB Typ C konektoroch
- [x] Mikrokontrolér by nemal byť vstrede ale na kraji keďže používame zreťazené registre.
- [x] Medzera medzi bankami s číslami hodín a minút by nemala presiahnuť 20mm (2x primer numitronu).
- [x] Medzera medzi bankami jednotlivých cifier čisiel by nemala presiahnuť 10mm (1x priemer numitronu).
- [x] Pri pajkovaní by vzdialenosť od pinov nemala byť menšia ako 3 mm (zvolili sme ~10mm).
- [x] Väčšie pady aspoň 2.2mm a diera 1.1mm
    - 95% pinov budú mať priemer pod 1mm, najmenší vrták je 1mm takže všetky diery ideálne chceme
      mať 1mm.
    - Aspoň milimiter materialu okolo diery pre istejšie leptanie.
    - Diery zväčšovať nebudeme, pady idealne ak by mali minimálne tak pol milimetra do každej strany.
    - Používame teardrops pre lepšiu spoľahlivosť pri vrtaní a odlievaní.
- [x] Poradie registrov bude netredične začínať jednotkami minút, pretože tak to vychádza
      podstatne lepšie na doske.
      - ~~Treba zistiť aké výhody a nevýhody toto potencionálne prinesie a aké veľké zmeny bude treba urobiť v prototype.~~
      - Zmien moc nie je, len sa zmení SERIN vstup a v kóde číslovanie registrov.
      - Veľké výhody ani optimalizácie v jedenom či druhom zapojení nevidím,
        keďže registre sú posuvné, pri zmene akéhokoľvek čísla musíme naposúvať
        všetky 4 čísla znovu.
- [x] Podpora signalizácie aj pre invertujúce DCF77 moduly.
    - LED-ka bude vyvedená zo MCU a ovládaná priamo DCF77 knižnicou, invertovanie vie byť ľahko zmenené v softvéri.
- [x] ~~Kapacitný trimmer pre detailné ladenie kryštálového oscilátora?~~
    - ~~Treba zistiť či nebude potrebný rezistor pre vybíjanie kondezátorov.~~ (Nepotrebuje, ATmega328p ho ma zabudovaný).
    - !!!! Problém je, že datasheet ATmega328p vyžaduje aby boli kondezátory C1 a C2 na XTAL1 a XTAL2 rovnaké.
    - Netreba úplne presný oscilátor, nemáme ho aj tak ako zmerať.
- [x] Jas signalizačnej LED-ky by mal byť upraviteľný pomocou trimmeru, bez potreby úpravy softvéru.
    - Keďže budeme používať RGB diódu, priamo zapojený jeden trimmer nestačí,
      no na tri pre každú farbu nie je miesto ani to nie je uživateľský prívetivé.
    - ~~Použijeme preto digitálny trimmer s offsetom?~~
        - Offset aj step vieme nastaviť softvérovo.
- [x] Bezpečnostný obvod pre CR2032 batériu (od PANASONIC) podľa pomerne prísnych noriem od UL.
    - Obvod by mal obsahovať buď dve blokujúce diódy v sérií alebo jednu blokujúcu diódu
      a jeden rezistor tiež v sérií.
    - Použité diódy by mali byť krémikové (lat. silicium) aby zvodový prúd nepresiahol
      1% celkovej kapacity batérie počas jej života. Akýkoľvek väčší zvodový prúd ktorý
      by nabíjal batériu, ju môže poškodiť a tak skrátiť jej životnosť.
    - https://cr2032.co/protection-circuit-article.html
    - BUDE ZAHRNUTÉ V DS3231 RTC čípe.
- [x] Bolo by zaujimavé vytvoriť vlastnú anténu pre DCF77. Na to ale budeme potrebovať:
    - feritovú tyč aspoň 10x100mm (Aliexpress).
    - vynutie na cievku 0.3-0.5mm (AliExpress).
    - Indukčnosť vynutia z jádrom chceme mať okolo 5-10mH, aby sa veľkosť kondezátora
      pohybovala v pF pre presnejšie ladenie pomocou kapacitného trimmera.
    - Kondezátor by sa mal dávať radšej na anténu ako na samotný príjimací obvod,
      aby sme mohli anténu kedykoľvek jednoducho vymeniť.
    - tester tranzistorov s meraním indukčnosti a kapacity (Aliexpress).
    - ak by sme chceli byť hodne presný, treba generátor frekvencie a osciloskop.
    (https://www.aliexpress.com/item/1005007476871321.html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)
    - Anténa vypadá rezonovať pri frekvencii 77.5KHz pomerne presne.
- [x] Pre vyriešenie problémov z presnosťou hodín na slepo (bez DCF77 synchronizácie)
      môžeme použiť modul HW-84 s RTC čipom DS3231-SN (industrial).
      Zároveň tým vyriešime problémy s pozíciou a bezpečným zapojením 3V mincovej Li batérie
      (modul čip spĺňa podmienky UL pre ochranu pred spätným prúdom).
    - Modul vypadá byť zapojený pomerne dobre, akurát treba odstrániť dva rezistory:
        - jeden pred diódov signalizujúcou externé napájanie a jeden pred
          nabíjacou diódov (budeme používať CR2032 ktoré nie sú nabijateľné).
    - Modul má aj senzor teploty (+- 3 °C).
    - Existujú dve verzie čipu DS3231-M (menej presný) a DS3231-SN (lepší).
- [x] Bloková schéma (na samostatnú stranu?).
- [x] RESET obvod (zabezpečenie proti viacerím resetom).
- [x] Ferit na VBUS?
    - Zmenší rušenie a zabráni nárazovým prúdom pri pripojení do siete.
    - Dovolí mať väčšiu kapacitu než predpisuje špecifikácia pre USB.
        - Treba zistiť o koľko.
- [x] RESET obvod detekcia dlhého podržania (vymaže EEPROM a konfigurácie).
    - Pripojením RESET pinu na digitálny pin.
    - Treba otestovať na doske.
- [x] Všetky elektrolyti ak je to možné, nahradiť keramikou.
    - Je treba si dať pozor na prudký pokles napätia pri prvom spustení hodín
      (hlavne pri rozsvietení displeja).
    - Pri keramika treba počítať s napäťovým skreslením.
    - Všade používať dielektrikum X7R alebo lepšie.
    - 100nF kondezátor.
    - Treba zistiť koľko kapacity naozaj potrebujeme.
        - Ak bude treba rádovo viac ako 10uF, je treba implementovať soft-start obvod cez výkonový MOSFET.
    - Zatiaľ necháme keramiku, ak by to robilo problémy, nahradíme ľahko.
- [x] Ochrana pred napájaním z ISCP zbernica a USB-C konektora zároveň.
    - Využijeme ON-ON spínač
    - Treba si dať pozor aby nespájal oba vývody, možno použiť ON-OFF-ON?
    - V jednej polohe prepojí VBUS s VCC a v druhej VCC_ICSP s VCC.
- [x] Kryštáľ treba nízky +8MHz s chybovosťou <=30ppm
    - Stačí aj 30ppm keďže už ho nebudeme používať na presné počítanie času.
    - Čím vyššia frekvencia, tým vyššia spotreba aj keď v našom prípade je spotreba čipu
      zastienená spotrebou numitronou, takže je zanedbateľná.
    - Keďže MCU už nebude bežať cez batériu, spotrebu netreba riešiť.
    - Použíjeme 16MHz kryštáľ pretože bol používaný pri testovaní a ponúka veľkú flexibilitu.
    - Treba otestovať na doske.
    - [ ] Treba ešte doladiť kryštáľ.
- [x] Zväčšiť šírku všetkých čiar a textu na strane súčiastok.
~~- [-] Možnosť komunikácie cez USB C port?~~
    ~~- D+ a D- pripojené na niektoré piny ATMEGA328 cez jumpre.~~
    https://www.youtube.com/watch?v=6U_bHTnFu-g
    https://www.obdev.at/products/vusb/index.html
    - Teoreticky možné ale zbytočné pretože tak jednoduchý firmvér by nemal potrebovať aktualizácie
      ak aj áno, pre vývoj firmvéru je treba mať hodiny fyzicky u seba pre testovanie.
- [x] Detekcia poruchy segmentov (zatiaľ len manuálna diagnostika).
    - Pred každý register 1 Ohm rezistor ktorý bude merať prúdový odber.
        - Treba zistiť aký to bude mať dopad na jas a aká bude presnosť takéhoto merania.
    - Máme zápojenie s jedným 1R rezistorom ktorý napája celý displej,
      jeho úbytok je zosílený v rozdielovom zosiľňovači.
    - Toto nám dá pomerne schopný spôsob ako merať odber prúdu displeja
      alebo aspoň jednotlivých numitronov.
    - Zároveň by tento obvod mal ísť softvérovo vypnuť v prípade že sa niečo pokazí
      (napríklad vplyvom stárnutia súčiastok), a detektor by chybne detekoval poruchy.
        - No konfigurácia cez obrazovku hodín nie je ideálne pretože pri poruche
          by detekcia vypla čásť alebo celý displej, takže by hodiny nebolo možné konfigurovať.
    - Použijeme OZ alebo jednoduchý tranzistorový obvod?
    - INA219? Pripájať by mala ísť. Slušná presnosť, cena okolo 3 eur.

# Pájkovanie
- [x] Pasta na ošetrenie medennej dosky proti korózií a skratom. (má čas ale dôležité pre finálny výsledok)
    - Dorazí začiatkom septembra.
~~- [ ] Doska nastriekaná na čierno a text (silkscreen) biely pre lepší kontrast?~~
    - Nemáme odkiaľ vziať biely text, keďže nemáme farebnú laserovú tlačiareň.
- ~~[ ] Resetovateľné polymérové poistky by mali byť osadené aj pri každom registre namiesto zbytočných jumper káblov.~~
    - Registre majú síce 500mA limit pre každý kanál (tento limit klesá s rastúcou teplotou),
      ale cez kanály by nemalo ísť viac ako 150mA dlhodobo.
    - Poistka by mala mať čo najmenší odpor v neaktivovanom stave
    - Limit registrov stačí.

# Software
- [x] Všetky piny by mali mať definovaný stav.
~~- [ ] Počítadlo prevádzkových hodín?~~
- [ ] Ukládať nastavenia do EEPROM.
    - Nejaký systém na zistenie chýb prip. aj ich opravy.
    - Dáta sa budú ukládať cyklicky aby sa zvýšila životnosť EEPROM.
- [x] Animácie pri štarte, prip. pri kontrole segmentov.
- [x] Pri štarte rozsvietiť všetky segmenty.
~~- [ ] Vypnúť ADC prevodníky na všetkých pinoch kde sa nepoužíva.~~
    - Nejdú vypnúť separátne len globálne.
~~- [ ] V prípade detekcie odpojenia zo siete, prenúť do úsporného režimu.~~
    - Nie je potrebné, keďže MCU nebude bežať na batérii.
- [ ] Väčší debouncy delay pre tlačítka aby sa počítalo aj s opotrebovaním.
    ~~- Zároveň budeme musieť pravepodobne použiť externé prerušenia.~~
    - Externé prerušenie nie sú vhodné pre bežné ovládacie tlačidlá, pretože
      tie sú často klikané a tým dojde k zaplaveniu zbernice prerušení.
    - Používame externé 100n kondezátory, ktoré tento bounce efekt výrazne zmenšujú.
- [x] Plynulý prechod z jedného čisla na druhé pomocou PWM (podobne ako u danyka, nie len fading-in).
    - Používame rýchle striedanie starých čisiel za nové s pomaly sa znížujúcou frekvenciou starých v prospech nových.
- [ ] Tlačítko na manuálne zahájenie synchronizácie (kombinácia tlačidiel).
    ~~- Tlačítko s LED-kou ktorá ide stačiť pre zahajenie synchronizácie?~~ (ťažko zohnateľné).
    - V nastaveniach bude možnosť vypnúť automatickú synchronizáciu,
      po vypnutí a zapnutí sa synchronizácia okamžite zaháji.
- [ ] Zapnúť brownout ako ochranu pred slabím zodrojom (nastaviť na čo najvyššiu hodnotu).
    - Defaultne je nastavený na 2.7V pre arduino UNO, keďže máme napájanie cez USB-C bolo by dobré toto zmeniť na 4.3V.
- [ ] Zapnúť watch-dog ako ochranu pred zaseknutím aby sa zaistilo, že hodiny ukazujú vždy len správny
      čas alebo sú vypnuté v prípade chyby.
      - Aký má vyznam zapínať watchog cez fuses ak sa to dá aj cez samotný firmware?

# Krabička
- [ ] Vyber dreva (pravdepodobne Buk?) (ebony, cherry, akacia, ...).
~~- [ ] Rozmery podľa archy zmluvy? (2.5:2.5:1.5)~~
- [ ] Pod ovládacím panelom citát z knihy Numeri + venovanie k 50-tým narodeninám pod tým.
    - NUMERI 4:30?
- [ ] Zospodu krabičky mená ľudí, ktorý spolupracovali, ZVL-ka (logo?).
~~- [ ] Závažia do krabičky aby bola stabilnejšia a masivnejšia.~~
 - Bude z betónu!
- [x] Tlačítka zo zadu na krajoch krabičky (najväčší priemer ~10mm);
- [ ] Zohnať zdroj s USB C káblom určený na dlhodobé napájanie.
    - Väčšina bežných mobilných nabíjačiek su v podstate len 5V (+-0.5V) zdroje s trafom
      takže pokiaľ nabíjačka podoporuje aspoň 1A, môže byť použítá na napájanie hodín.
    - Treba si dať pozor oceľová káble (kontrola magnetom). Vždy len meď!
    - Zdroj musí byť veľmi dobre odrušený aby nezarušil DCF77 prijímač,
      rádioamatéri odporúčajú originálne nabíjačky od Apple.
- [x] Treba zohnať hlinikový kufor pre anténu.
    - [ ] Treba zohnať ešte väčší kufor pre samotné hodiny (hlavne vyšší).

# Implementácia
- [x] QR kód z logom obce s odkazom na online návod.
    - Logo obce nakoniec nebude pretože by QR-kód musel byť príliš veľky aby bolo vidno.
    - Po nalepení sa treba uistiť, že QR-kód je čítateľný.
    - Postup práce, fotky...
- [x] Zohnať laserovú tlačiareň.
    - [x] Treba sa uistiť, že je dobre nastavený scale a že tlačí naozaj 1:1.
    - [x] Upraviť nastavenie aby bola kvalita tlače čo najlepšia
          a prípadne nastaviť typ papiera. (1200 namiesto 600)
    - [x] Zohnať nový originálny toner.
- [x] Rýchloschnúci ochranný lak (napr. na nechty), pre ochranu masky súčiastok.
    - Použili sme Belton Racing lak keďže lak na vlasy sa ukázal ako nevhodný.
- [x] Zohnať lepší DCF77 modul prípadne väčšiu feritovú anténu (ideálne 100x10mm).
    - Po integrovaní DCF77 demodulačnej knižnice od Uda Kleina príjimač nemusí byť excelentný.
    - Otázka ale je aký vplyv bude mať jeho osadenie v pomerne nízkej (30mm) krabičke plnej elektroniky.
        - Treba zajistiť aby PWM signál ktorým modulujeme G pin registrov mal f > 100 kHz
- [x] Využiť potenciál vrchnej masky zo strany súčiastok (označovanie oblastí, pomoc pri oprave).
    - Pozor: Toner sa bude pravdepodobne taviť pri pajkovaní.
~~- [ ] DCF77 modul od: ~~
 - https://de.elv.com/dcf-empfangsmodul-dcf-2-091610?fs=690476457
 - 10 EUR voucher do 17.8.2025
 - Dodanie len do nemecka.
- [ ] Na stránke 3D model hodín ~~(.stl) pre github.~~
      - (STL zobrazuje len bezfarebný vektorový model s veľmi malým rozlíšením detailov).
      - Lepšie bolo použiť zobrazovače modelov priamo od AutoCADu.
        (https://aps.autodesk.com/en/docs/viewer/v7/developers_guide/)
      - Model pred pridaním treba optimalizovať cez stránku (https://converters.plugxr.com/glb/optimize)
      - Vytvoriť model hodín aj s podstavou a tlačítkami (kompletný)
         - Stránka umožní "skryť" tento podstavec alebo len jeho časti,
           aby sa odhalili útroby hodín.
- [ ] Pridať fotky na stránku, v chronologickom poradí, možnosť filtrovania,

# Manuál
- [x] Historia numitronov IV-9.
- [ ] Prepísať na písacom stroji na starý zahnedlý papier.
    - [ ] Použiť normálny papier namočený v čiernom čaji?
- [ ] Pre obrázky použiť len čiernobiele obrysy s retro filtrom.
- [ ] Treba oldschool spojitú schému vytlačenú na A3/A2 ktorá sa vloží do manuálu v prípade
      potreby opráv.
      - Môžeme ponechať aj aktuálnu len s miernými úpravami (obrázky preč, čiernobiela...).
-

https://www.vpcentrum.eu/pic16f1825-e-p-mikrokontroler-pic-eeprom-256b-sram-1024b-32mhz-dip14
https://www.vpcentrum.eu/pic16f1825-i-p-mikrokontroler-pic-eeprom-256b-sram-1024b-32mhz-dip14
https://www.vpcentrum.eu/pic16f18426-i-p-mikrokontroler-pic-pamet-28kb-sram-2048b-eeprom-256b-32mhz

https://www.mouser.sk/ProductDetail/Microchip-Technology/PIC16F17126-I-P?qs=t7xnP681wgXtcSE8l0tHNA%3D%3D
https://www.youtube.com/watch?v=aIWxFjGh_HY

# Pozorovania
- Nemôžeme použiť interný kryštál pretože aj dekódovanie DCF signálu vyžaduje presný oscilátor.
- Programovanie ATMEGA cez ICSP prepíše celú flash pamäť vrátane bootloadera ktorý je na jej samom konci.
    - Preto po programovaní cez ICSP treba napáliť bootloader aby fungoval Arduino UNO shield.
- [AVR hardware design considerations](https://ww1.microchip.com/downloads/en/appnotes/atmel-2521-avr-hardware-design-considerations_applicationnote_avr042.pdf)
- https://www.we-online.com/catalog/media/o109030v410%20AppNotes_ANP002_TheProtectionOfUSB20Applications_EN.pdf
- https://www.nemethelektronika.hu/termekek/led-rgb-5-mm-kozos-anos-dis6103

https://www.nixiekits.eu/Downloads/USB_Nixie_Clocks_Aufbauanleitung.pdf
https://www.youtube.com/watch?v=cKjI08CTv54

----------------------------------------------------

Objednávky:obr
~~https://www.vpcentrum.eu/ina181a2idbvr-ic-operacni-zesilovac~~
1x https://www.vpcentrum.eu/soucastky-nahradni-dily/diody/transily/jednosmerne-tht/dioda-transil-1-5kw-6v-200a-jednosmerny
3x https://www.vpcentrum.eu/soucastky-nahradni-dily/diody/transily/jednosmerne-tht/dioda-transil-600w-6-45v-57a-jednosmerny-do15
https://www.vpcentrum.eu/soucastky-nahradni-dily/kondenzatory/keramicke/kondenzator-keramicky-mlcc-monoliticky-100nf-100v-x7r-10-2
https://www.vpcentrum.eu/soucastky-nahradni-dily/kondenzatory/keramicke/kondenzator-keramicky-mlcc-1uf-25vdc-x7r-10-tht-5mm-1
https://www.vpcentrum.eu/soucastky-nahradni-dily/patice-a-piny/patice-1/dil28-patice-obycejna-rm-2-54-uzka-pro-cache-7-62mm
https://www.vpcentrum.eu/soucastky-nahradni-dily/patice-a-piny/piny-hrebeny/kolikova-lista-kolikove-vidlice-pin-6-primy-2-54mm-tht-2x3
3x https://www.vpcentrum.eu/soucastky-nahradni-dily/kondenzatory/keramicke/kondenzator-keramicky-mlcc-4-7uf-25vdc-x7r-10-tht-2-5mm-1
https://www.vpcentrum.eu/kondenzator-keramicky-100nf-100v-x7r-10-tht-5mm-4
~~https://www.vpcentrum.eu/9k1-tr191-rezistor-0-25w/soucastky-nahradni-dily/rezistory-tht-a-smd~~
2x https://www.vpcentrum.eu/soucastky-nahradni-dily/patice-a-piny/piny-hrebeny/propojka-kolikove-zasuvka-otevrene-2-54mm-1x2-cervena
2x https://www.vpcentrum.eu/soucastky-nahradni-dily/patice-a-piny/piny-hrebeny/propojka-kolikove-zasuvka-otevrene-2-54mm-1x2-modra
6x https://techfun.sk/produkt/svorka-2-piny-zelena-2-54-mm/§
5x (10K, 1K) https://techfun.sk/produkt/trimmer-typu-3362-rozne-varianty/
5x https://www.vpcentrum.eu/30r-tr191-rezistor-0-25w
// do multimetra
https://www.vpcentrum.eu/pojistka-tavna-rychla-sklenena-2a-250vac-5x20mm-mosaz-2

https://www.youtube.com/watch?v=oI0Fgdkzbgg

Testovanie RC8000 modulu (28.07.2025)
- Po odpajkovaní antény a kondezátora tvoriaceho LC rezonančný obvod asi došlo k poškodeniu
  modulu pretože po opätovnom pripojení tej istej antény a kondezátora aj keď cez káble
  (zanedbateľne zvýšený odpor), modul rozsviecuje LED-ku len pri veľmi silných vlnách.
- Pripojenie veľkej (10x140mm) atény s jej príslušných kondenzátorom má veľmi podobné výsledky,
  aj keď takéto zapojenie je pozorovateľne viac citlivejšie, stále to nestačí na zachytenie
  slabého DCF77 signálu ani okolitého rušenia (napr. mobil, PC).

----------------------------------------------------

(Pre krystalove radio)
[x] - https://www.aliexpress.us/item/4000120540895.html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

ZDROJE:
https://www.g8wrb.co.uk/data/Burle/Techniques-to-Extend-the-Service-Life-of-High-Power-Vacuum-Tubes.pdf
https://electronics.stackexchange.com/questions/717967/pwm-dimming-of-a-low-voltage-dc-incandescent-filament-thermal-shock

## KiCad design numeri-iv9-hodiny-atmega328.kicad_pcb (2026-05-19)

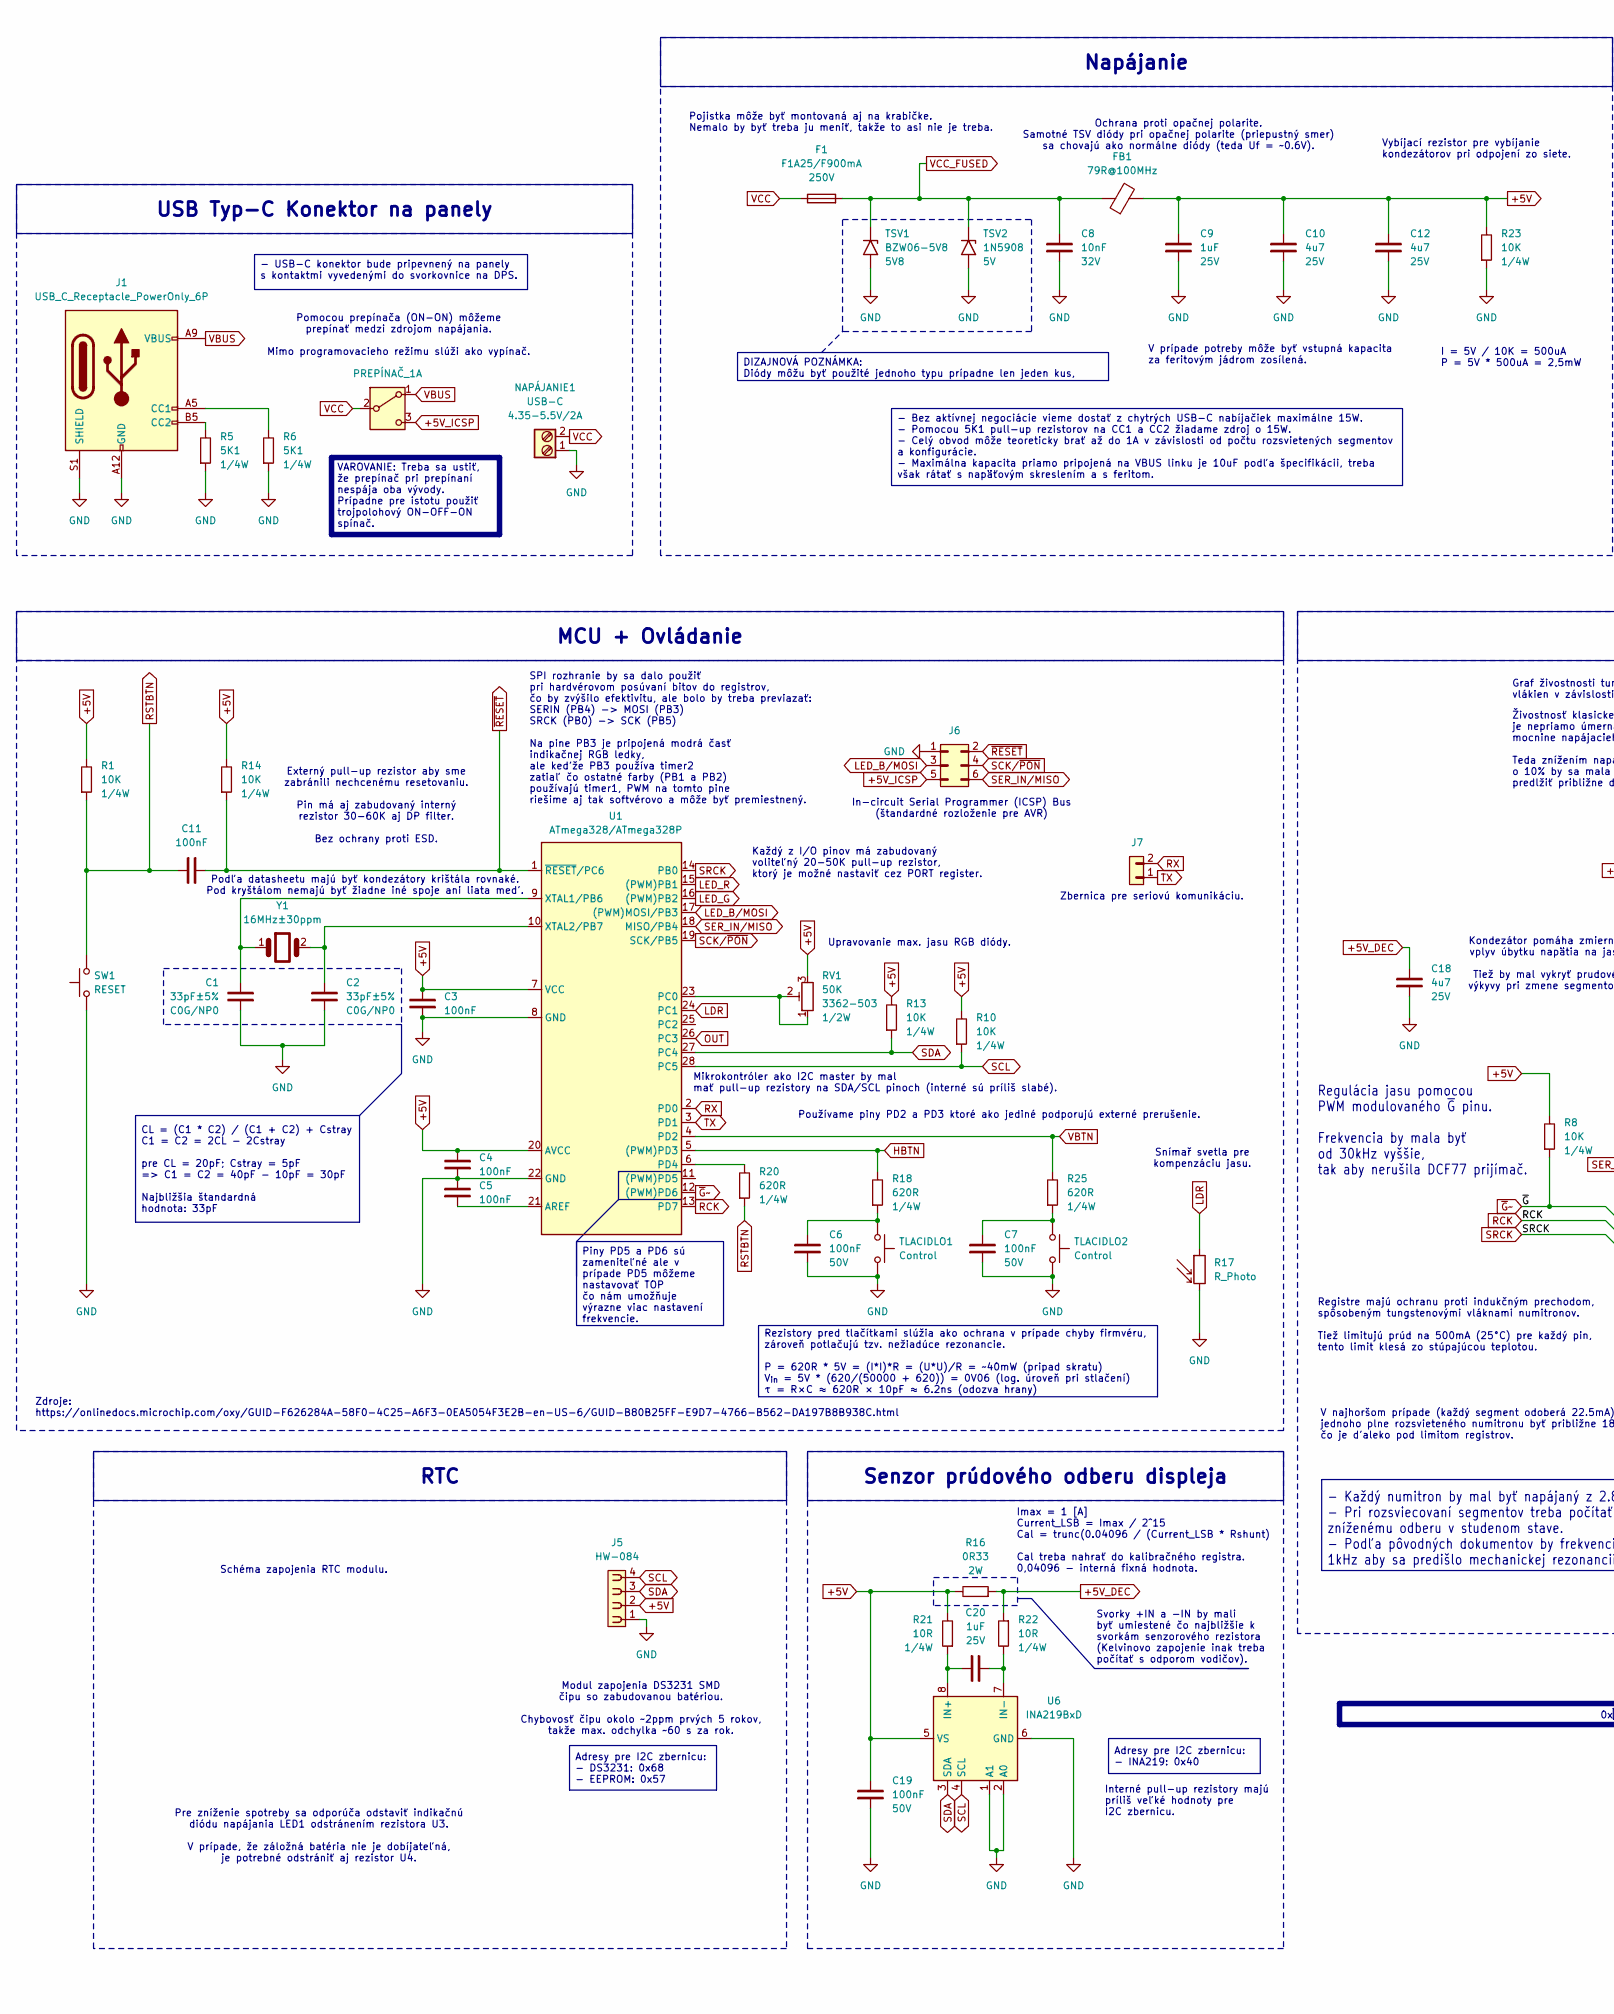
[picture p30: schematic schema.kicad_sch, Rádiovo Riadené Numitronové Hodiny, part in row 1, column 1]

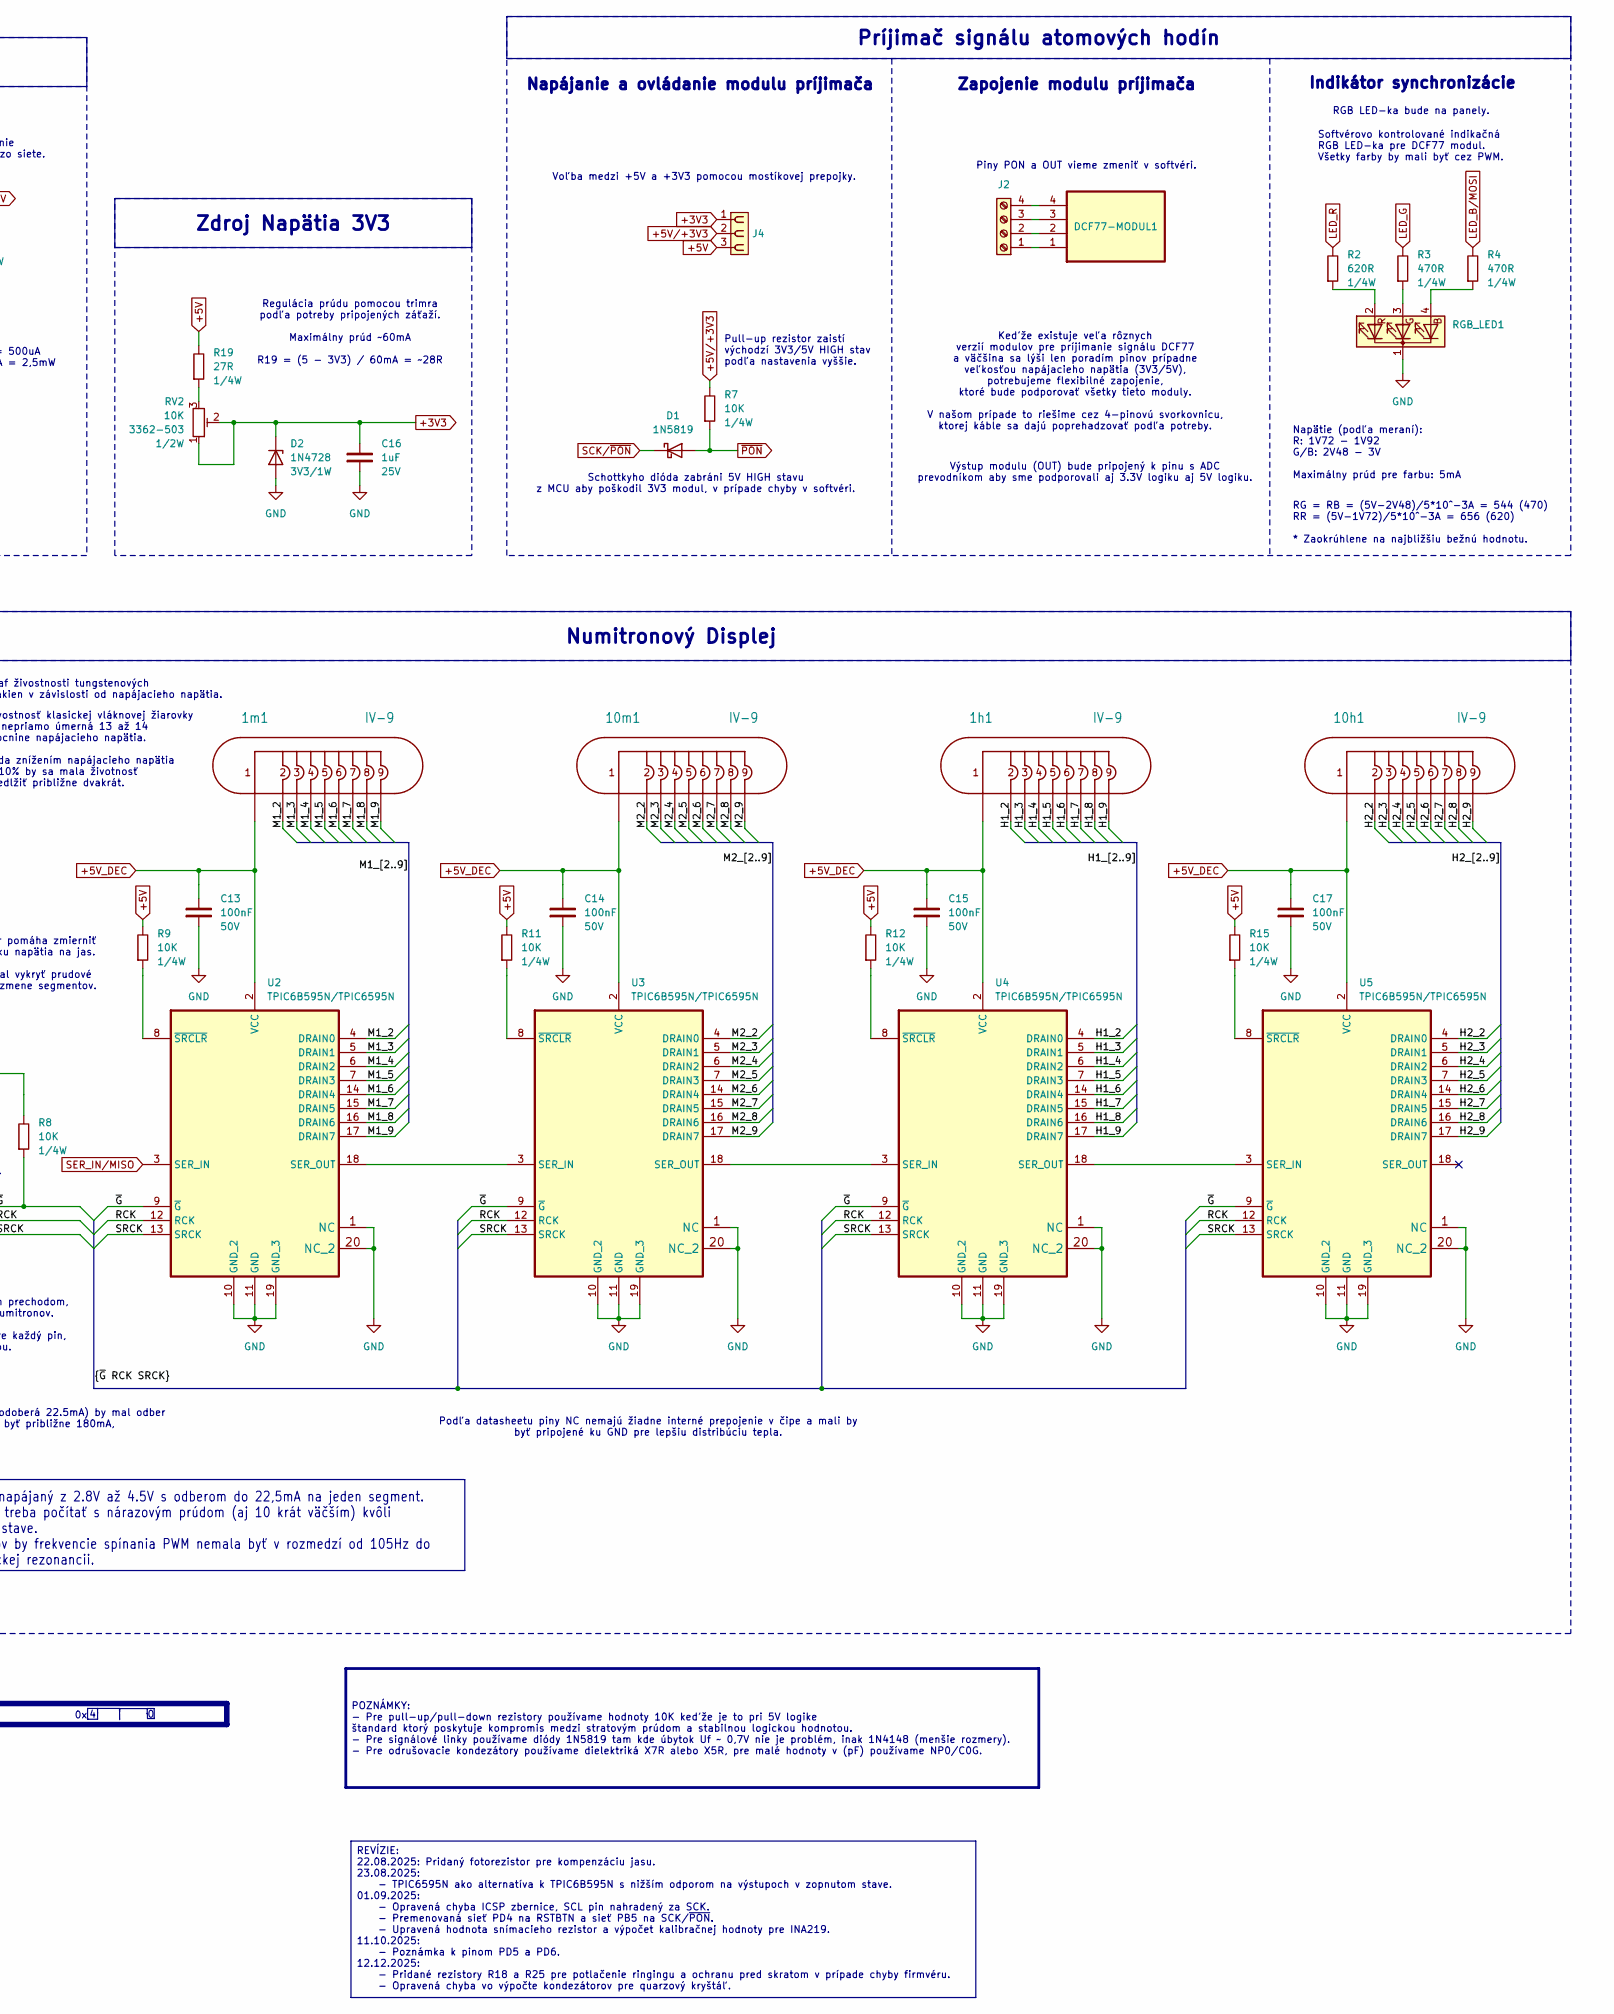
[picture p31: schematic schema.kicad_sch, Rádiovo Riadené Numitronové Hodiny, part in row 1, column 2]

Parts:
1h1, 1m1, 10h1, 10m1: IV-9; IV-9_External_Socket_Asymetric
C1, C2: 33pF±5%; C_Disc_D6.0mm_W2.5mm_P5.00mm
C3, C4, C5, C6, C7, C11, C13, C14, C15, C17, C19: 100nF; C_Disc_D6.0mm_W2.5mm_P5.00mm
C8: 10nF; C_Disc_D6.0mm_W2.5mm_P5.00mm
C9, C16, C20: 1uF; C_Disc_D6.0mm_W2.5mm_P5.00mm
C10, C12, C18: 4u7; C_Disc_D6.0mm_W2.5mm_P5.00mm
D1: 1N5819; D_DO-41_SOD81_P7.62mm_Horizontal
D2: 1N4728; D_DO-35_SOD27_P7.62mm_Horizontal
DCF77-MODUL1: DCF77; PinSocket_1x04_P2.54mm_Vertical
F1: F1A25/F900mA; Fuseholder_Cylinder-5x20mm_Schurter_0031_8201_Horizontal_Op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; Voltage 250V
FB1: 79R@100MHz; L_Axial_L5.0mm_D3.6mm_P10.00mm_Horizontal_Murata_BL01RN1A2A2
J1: USB_C_Receptacle_PowerOnly_6P
J2: Screw_Terminal_01x04; PinSocket_1x04_P2.54mm_Vertical
J4: PINHD_1x3_Female; PinHeader_1x03_P2.54mm_Vertical
J5: HW-084; HW_84
J6: 2x3; PinHeader_2x03_P2.54mm_Vertical
J7: 1x2; PinSocket_1x02_P2.54mm_Vertical
NAPÁJANIE1: USB-C; TerminalBlock_Phoenix_PT-1,5-2-5.0-H_1x02_P5.00mm_Horizontal
PREPÍNAČ_1: SW_DPDT_x2
R1, R8, R9, R11, R12, R14, R15: 10K; R_Axial_DIN0207_L6.3mm_D2.5mm_P7.62mm_Horizontal
R2, R18, R20, R25: 620R; R_Axial_DIN0207_L6.3mm_D2.5mm_P7.62mm_Horizontal
R3, R4: 470R; R_Axial_DIN0207_L6.3mm_D2.5mm_P7.62mm_Horizontal
R5, R6: 5K1; R_Axial_DIN0207_L6.3mm_D2.5mm_P10.16mm_Horizontal
R7: 10K; R_Axial_DIN0207_L6.3mm_D2.5mm_P15.24mm_Horizontal
R10, R13: 10K; R_Axial_DIN0207_L6.3mm_D2.5mm_P5.08mm_Vertical
R16: 0R33; R_Axial_DIN0414_L11.9mm_D4.5mm_P20.32mm_Horizontal
R17: R_Photo
R19: 27R; R_Axial_DIN0207_L6.3mm_D2.5mm_P10.16mm_Horizontal
R21, R22: 10R; R_Axial_DIN0207_L6.3mm_D2.5mm_P7.62mm_Horizontal
R23: 10K; R_Axial_DIN0207_L6.3mm_D2.5mm_P10.16mm_Horizontal
RGB_LED1: RGB_LED; JST_XH_B4B-XH-A_1x04_P2.50mm_Vertical
RV1: 50K; potentiometer_3362P
RV2: 10K; potentiometer_3362P
SW1: RESET; SW_PUSH_6mm
TLACIDLO1, TLACIDLO2: Control; TerminalBlock_Phoenix_PT-1,5-2-5.0-H_1x02_P5.00mm_Horizontal
TSV1: BZW06-5V8; D_DO-15_P12.70mm_Horizontal; Voltage 5V8
TSV2: 1N5908; D_DO-15_P12.70mm_Horizontal; Voltage 5V
U1: ATmega328/ATmega328P; DIP-28_W7.62mm_Socket
U2, U3, U4, U5: TPIC6B595N/TPIC6595N; DIP-20_W7.62mm_Socket_With_IC
U6: INA219BxD; SOIC-8_3.9x4.9mm_P1.27mm
Y1: 16MHz±30ppm; Crystal_HC49-4H_Vertical

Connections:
+3V3: C16.2, D2.1 (K), J4.1, RV2.1, RV2.2
+5V: C3.2, C4.2, C9.2, C10.2, C12.2, C19.2, FB1.2, J4.3, J5.2, R1.2, R8.2, R9.2, R10.2, R11.2, R12.2, R13.2, R14.2, R15.2, R16.2, R19.2, R21.2, R23.2, RV1.3, U1.7 (VCC), U1.20 (AVCC), U6.5 (VS)
+5V_DEC: 1h1.1, 1m1.1, 10h1.1, 10m1.1, C13.2, C14.2, C15.2, C17.2, C18.2, R16.1, R22.1, U2.2 (VCC), U3.2 (VCC), U4.2 (VCC), U5.2 (VCC)
+5V_ICSP: J6.5, PREPÍNAČ_1.3 (C)
+5V/+3V3: J4.2, R7.2
/Hlavná Schéma/H1_2: 1h1.2, U4.4 (DRAIN0)
/Hlavná Schéma/H1_3: 1h1.3, U4.5 (DRAIN1)
/Hlavná Schéma/H1_4: 1h1.4, U4.6 (DRAIN2)
/Hlavná Schéma/H1_5: 1h1.5, U4.7 (DRAIN3)
/Hlavná Schéma/H1_6: 1h1.6, U4.14 (DRAIN4)
/Hlavná Schéma/H1_7: 1h1.7, U4.15 (DRAIN5)
/Hlavná Schéma/H1_8: 1h1.8, U4.16 (DRAIN6)
/Hlavná Schéma/H1_9: 1h1.9, U4.17 (DRAIN7)
/Hlavná Schéma/H2_2: 10h1.2, U5.4 (DRAIN0)
/Hlavná Schéma/H2_3: 10h1.3, U5.5 (DRAIN1)
/Hlavná Schéma/H2_4: 10h1.4, U5.6 (DRAIN2)
/Hlavná Schéma/H2_5: 10h1.5, U5.7 (DRAIN3)
/Hlavná Schéma/H2_6: 10h1.6, U5.14 (DRAIN4)
/Hlavná Schéma/H2_7: 10h1.7, U5.15 (DRAIN5)
/Hlavná Schéma/H2_8: 10h1.8, U5.16 (DRAIN6)
/Hlavná Schéma/H2_9: 10h1.9, U5.17 (DRAIN7)
/Hlavná Schéma/M1_2: 1m1.2, U2.4 (DRAIN0)
/Hlavná Schéma/M1_3: 1m1.3, U2.5 (DRAIN1)
/Hlavná Schéma/M1_4: 1m1.4, U2.6 (DRAIN2)
/Hlavná Schéma/M1_5: 1m1.5, U2.7 (DRAIN3)
/Hlavná Schéma/M1_6: 1m1.6, U2.14 (DRAIN4)
/Hlavná Schéma/M1_7: 1m1.7, U2.15 (DRAIN5)
/Hlavná Schéma/M1_8: 1m1.8, U2.16 (DRAIN6)
/Hlavná Schéma/M1_9: 1m1.9, U2.17 (DRAIN7)
/Hlavná Schéma/M2_2: 10m1.2, U3.4 (DRAIN0)
/Hlavná Schéma/M2_3: 10m1.3, U3.5 (DRAIN1)
/Hlavná Schéma/M2_4: 10m1.4, U3.6 (DRAIN2)
/Hlavná Schéma/M2_5: 10m1.5, U3.7 (DRAIN3)
/Hlavná Schéma/M2_6: 10m1.6, U3.14 (DRAIN4)
/Hlavná Schéma/M2_7: 10m1.7, U3.15 (DRAIN5)
/Hlavná Schéma/M2_8: 10m1.8, U3.16 (DRAIN6)
/Hlavná Schéma/M2_9: 10m1.9, U3.17 (DRAIN7)
GND: C1.1, C2.1, C3.1, C4.1, C5.2, C6.1, C7.1, C8.1, C9.1, C10.1, C12.1, C13.1, C14.1, C15.1, C16.1, C17.1, C18.1, C19.1, D2.2 (A), J1.A12 (GND), J1.B12 (GND), J1.S1 (SHIELD), J5.1, J6.1, NAPÁJANIE1.1, R5.1, R6.1, R17.2, R23.1, RGB_LED1.1 (K), SW1.1, TLACIDLO1.1, TLACIDLO2.1, TSV1.2 (A2), TSV2.2 (A2), U1.8 (GND), U1.22 (GND), U2.1 (NC), U2.10 (GND_2), U2.11 (GND), U2.19 (GND_3), U2.20 (NC_2), U3.1 (NC), U3.10 (GND_2), U3.11 (GND), U3.19 (GND_3), U3.20 (NC_2), U4.1 (NC), U4.10 (GND_2), U4.11 (GND), U4.19 (GND_3), U4.20 (NC_2), U5.1 (NC), U5.10 (GND_2), U5.11 (GND), U5.19 (GND_3), U5.20 (NC_2), U6.1 (A1), U6.2 (A0), U6.6 (GND)
HBTN: R18.2, U1.5 ((PWM)PD3)
LDR: R17.1, U1.24 (PC1)
LED_B/MOSI: J6.3, R4.2, U1.17 ((PWM)MOSI/PB3)
LED_G: R3.2, U1.16 ((PWM)PB2)
LED_R: R2.2, U1.15 ((PWM)PB1)
unnamed: C6.2, R18.1, TLACIDLO1.2
unnamed: C7.2, R25.1, TLACIDLO2.2
unnamed: J1.A5 (CC1), R6.2
unnamed: J1.A9 (VBUS), J1.B9 (VBUS), PREPÍNAČ_1.1 (A)
unnamed: J1.B5 (CC2), R5.2
unnamed: DCF77-MODUL1.1, J2.1
unnamed: DCF77-MODUL1.2, J2.2
unnamed: DCF77-MODUL1.3, J2.3
unnamed: DCF77-MODUL1.4, J2.4
unnamed: R19.1, RV2.3
unnamed: R4.1, RGB_LED1.4 (BA)
unnamed: R3.1, RGB_LED1.3 (GA)
unnamed: R2.1, RGB_LED1.2 (RA)
unnamed: C5.1, U1.21 (AREF)
unnamed: RV1.1, RV1.2, U1.23 (PC0)
unnamed: R20.2, U1.6 (PD4)
unnamed: C1.2, U1.9 (XTAL1/PB6), Y1.1
unnamed: C2.2, U1.10 (XTAL2/PB7), Y1.2
unnamed: U2.18 (SER_OUT), U3.3 (SER_IN)
unnamed: R9.1, U2.8 (~SRCLR)
unnamed: U3.18 (SER_OUT), U4.3 (SER_IN)
unnamed: R11.1, U3.8 (~SRCLR)
unnamed: U4.18 (SER_OUT), U5.3 (SER_IN)
unnamed: R12.1, U4.8 (~SRCLR)
unnamed: R15.1, U5.8 (~SRCLR)
unnamed: C20.1, R21.1, U6.8 (IN+)
unnamed: C20.2, R22.2, U6.7 (IN-)
OUT: U1.26 (PC3)
RCK: U1.13 (PD7), U2.12 (RCK), U3.12 (RCK), U4.12 (RCK), U5.12 (RCK)
RSTBTN: C11.2, R1.1, R20.1, SW1.2
RX: J7.2, U1.2 (PD0)
SCK/~PON: D1.1 (K), J6.4, U1.19 (SCK/PB5)
SCL: J5.4, R10.1, U1.28 (PC5), U6.4 (SCL)
SDA: J5.3, R13.1, U1.27 (PC4), U6.3 (SDA)
SER_IN/MISO: J6.6, U1.18 (MISO/PB4), U2.3 (SER_IN)
SRCK: U1.14 (PB0), U2.13 (SRCK), U3.13 (SRCK), U4.13 (SRCK), U5.13 (SRCK)
TX: J7.1, U1.3 (PD1)
VBTN: R25.2, U1.4 (PD2)
VCC: F1.1, NAPÁJANIE1.2, PREPÍNAČ_1.2 (B)
VCC_FUSED: C8.2, F1.2, FB1.1, TSV1.1 (A1), TSV2.1 (A1)
~G~: R8.1, U1.12 ((PWM)PD6), U2.9 (~G), U3.9 (~G), U4.9 (~G), U5.9 (~G)
~PON: D1.2 (A), R7.1
~RESET: C11.1, J6.2, R14.1, U1.1 (~RESET/PC6)

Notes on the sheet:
Napätie (podľa meraní): R: 1V72 - 1V92 G/B: 2V48 - 3V Maximálny prúd pre farbu: 5mA
Svorky +IN a -IN by mali byť umiestené čo najbližšie k svorkám senzorového rezistora (Kelvinovo zapojenie inak treba počítať s odporom vodičov).
Mikrokontróler ako I2C master by mal mať pull-up rezistory na SDA/SCL pinoch (interné sú príliš slabé).
Zbernica pre seriovú komunikáciu.
Piny PON a OUT vieme zmeniť v softvéri.
Voľba medzi +5V a +3V3 pomocou mostíkovej prepojky.
Snímař svetla pre kompenzáciu jasu.
Výstup modulu (OUT) bude pripojený k pinu s ADC prevodníkom aby sme podporovali aj 3.3V logiku aj 5V logiku.
Regulácia jasu pomocou PWM modulovaného ~{G} pinu. Frekvencia by mala byť od 30kHz vyššie, tak aby nerušila DCF77 prijímač.
Indikátor synchronizácie
Každý z I/O pinov má zabudovaný voliteľný 20-50K pull-up rezistor, ktorý je možné nastaviť cez PORT register.
Pojistka môže byť montovaná aj na krabičke. Nemalo by byť treba ju meniť, takže to asi nie je treba.
V najhoršom prípade (každý segment odoberá 22.5mA) by mal odber jednoho plne rozsvieteného numitronu byť približne 180mA, čo je ďaleko pod limitom registrov.
Napájanie a ovládanie modulu príjimača
Ochrana proti opačnej polarite. Samotné TSV diódy pri opačnej polarite (priepustný smer) sa chovajú ako normálne diódy (teda Uf = ~0.6V).
Zdroje: https://onlinedocs.microchip.com/oxy/GUID-F626284A-58F0-4C25-A6F3-0EA5054F3E2B-en-US-6/GUID-B80B25FF-E9D7-4766-B562-DA197B8B938C.html
RGB LED-ka bude na panely.
Imax = 1 [A] Current_LSB = Imax / 2^15 Cal = trunc(0.04096 / (Current_LSB * Rshunt) Cal treba nahrať do kalibračného registra. 0,04096 - interná fixná hodnota.
Pre zníženie spotreby sa odporúča odstaviť indikačnú diódu napájania LED1 odstránením rezistora U3. V prípade, že záložná batéria nie je dobíjateľná, je potrebné odstrániť aj rezistor U4.
In-circuit Serial Programmer (ICSP) Bus (štandardné rozloženie pre AVR)
I = 5V / 10K = 500uA P = 5V * 500uA = 2,5mW
Podľa datasheetu majú byť kondezátory krištála rovnaké. Pod kryštálom nemajú byť žiadne iné spoje ani liata meď.
Živostnosť klasickej vláknovej žiarovky je nepriamo úmerná 13 až 14 mocnine napájacieho napätia. Teda znížením napájacieho napätia o 10% by sa mala životnosť predlžiť približne dvakrát.
Vybíjací rezistor pre vybíjanie kondezátorov pri odpojení zo siete.
SPI rozhranie by sa dalo použiť pri hardvérovom posúvaní bitov do registrov, čo by zvýšilo efektivitu, ale bolo by treba previazať: SERIN (PB4) -> MOSI (PB3) SRCK (PB0) -> SCK (PB5) Na pine PB3 je pripojená modrá časť indikačnej RGB ledky, ale keďže PB3 používa timer2 zatiaľ čo ostatné farby (PB1 a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
Upravovanie max. jasu RGB diódy.
Registre majú ochranu proti indukčným prechodom, spôsobeným tungstenovými vláknami numitronov. Tiež limitujú prúd na 500mA (25°C) pre každý pin, tento limit klesá zo stúpajúcou teplotou.
Keďže existuje veľa rôznych verzií modulov pre príjimanie signálu DCF77 a väčšina sa lýši len poradím pinov prípadne veľkosťou napájacieho napätia (3V3/5V), potrebujeme flexibilné zapojenie, ktoré bude podporovať všetky tieto moduly. V našom prípade to riešime cez 4-pinovú svorkovnicu, ktorej káble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
Pomocou prepínača (ON-ON) môžeme prepínať medzi zdrojom napájania. Mimo programovacieho režimu slúži ako vypínač.
Interné pull-up rezistory majú príliš veľké hodnoty pre I2C zbernicu.
Regulácia prúdu pomocou trimra podľa potreby pripojených záťaží. Maximálny prúd ~60mA R19 = (5 - 3V3) / 60mA = ~28R
RG = RB = (5V-2V48)/5*10^-3A = 544 (470) RR = (5V-1V72)/5*10^-3A = 656 (620) * Zaokrúhlene na najbližšiu bežnú hodnotu.
Schéma zapojenia RTC modulu.
Pull-up rezistor zaistí východzí 3V3/5V HIGH stav podľa nastavenia vyššie.
Externý pull-up rezistor aby sme zabránili nechcenému resetovaniu. Pin má aj zabudovaný interný rezistor 30-60K aj DP filter. Bez ochrany proti ESD.
Zapojenie modulu príjimača
Kondezátor pomáha zmierniť vplyv úbytku napätia na jas. Tiež by mal vykryť prudové výkyvy pri zmene segmentov.
Graf živostnosti tungstenových vlákien v závislosti od napájacieho napätia.
Používame piny PD2 a PD3 ktoré ako jediné podporujú externé prerušenie.
V prípade potreby môže byť vstupná kapacita za feritovým jádrom zosílená.

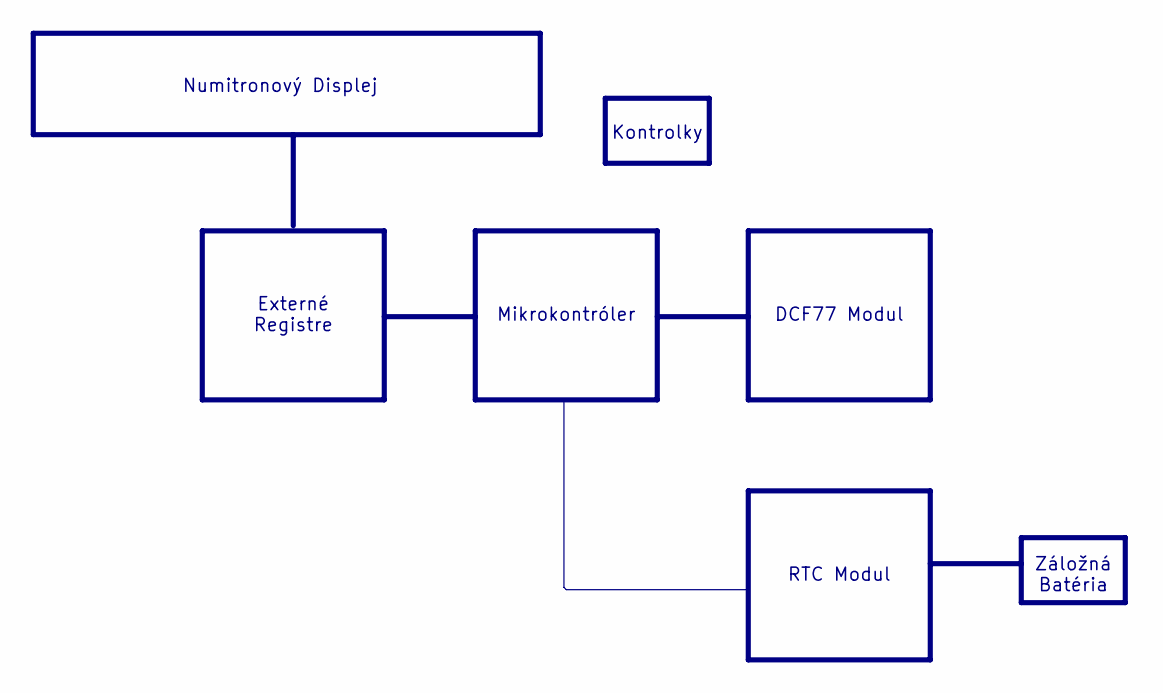
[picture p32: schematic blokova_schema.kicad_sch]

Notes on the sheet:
Externé Registre
Kontrolky
Numitronový Displej
DCF77 Modul
Záložná Batéria
RTC Modul
Mikrokontróler

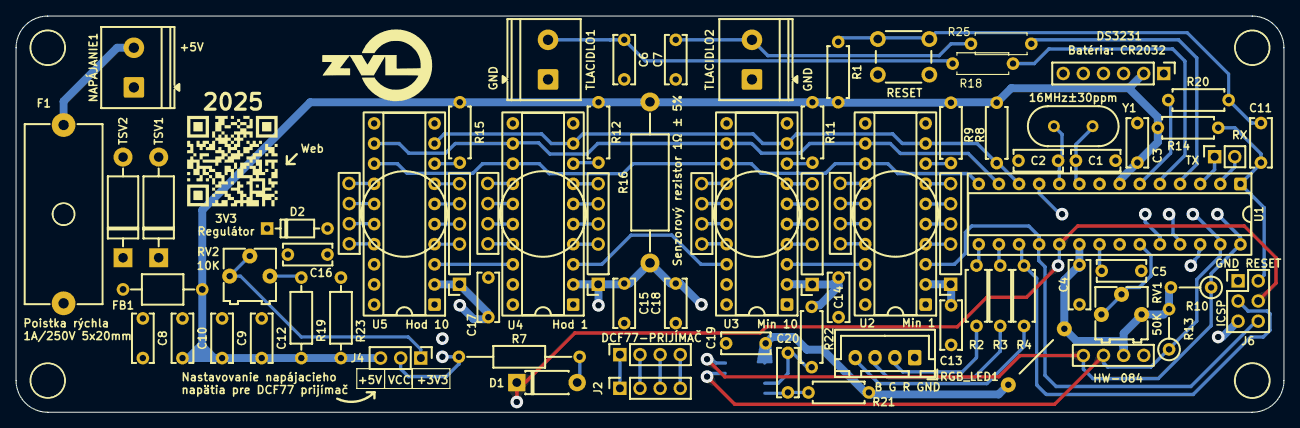
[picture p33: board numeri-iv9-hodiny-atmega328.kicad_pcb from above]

Board: 2 copper layers, 160.0 x 50.0 mm, 71 parts (1 on the bottom side), 80 nets.

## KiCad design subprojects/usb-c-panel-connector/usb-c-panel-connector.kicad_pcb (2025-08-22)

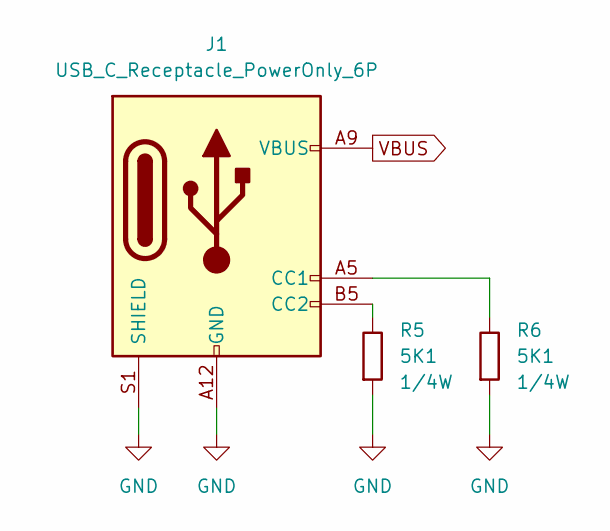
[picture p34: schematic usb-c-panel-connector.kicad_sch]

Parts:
J1: USB_C_Receptacle_PowerOnly_6P; USB_C_Receptacle_GCT_USB4125-xx-x-0190_6P_TopMnt_Horizontal
R5, R6: 5K1; R_1206_3216Metric

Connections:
GND: J1.A12 (GND), J1.B12 (GND), J1.S1 (SHIELD), R5.1, R6.1
unnamed: J1.A5 (CC1), R6.2
unnamed: J1.B5 (CC2), R5.2
VBUS: J1.A9 (VBUS), J1.B9 (VBUS)

Board: 2 copper layers, 3 parts (0 on the bottom side), 4 nets, no tracks yet.

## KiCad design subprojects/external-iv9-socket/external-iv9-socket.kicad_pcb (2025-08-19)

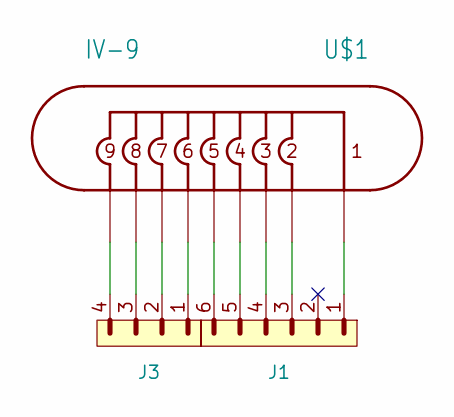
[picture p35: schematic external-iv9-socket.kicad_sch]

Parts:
J1: PINHD_1x6_Male; PinHeader_1x06_P2.54mm_Vertical
J3: PINHD_1x4_Male; PinHeader_1x04_P2.54mm_Vertical_MONO
U$1: IV-9; IV-9-Common-Separated

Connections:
unnamed: J1.1, U$1.1
unnamed: J1.3, U$1.2
unnamed: J1.4, U$1.3
unnamed: J1.5, U$1.4
unnamed: J1.6, U$1.5
unnamed: J3.1, U$1.6
unnamed: J3.2, U$1.7
unnamed: J3.3, U$1.8
unnamed: J3.4, U$1.9

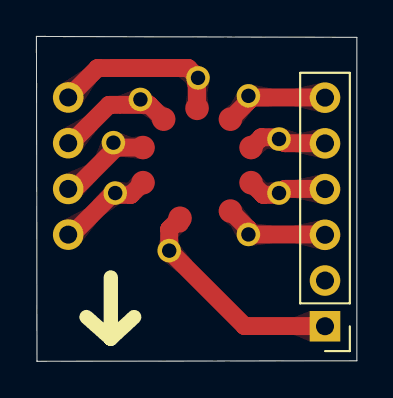
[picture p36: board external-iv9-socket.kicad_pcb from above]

Board: 2 copper layers, 17.8 x 18.0 mm, 3 parts (1 on the bottom side), 9 nets.

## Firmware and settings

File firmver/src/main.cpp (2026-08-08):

#include <avr/wdt.h>

#include "utils/math.h"
#include <serial.h>

#include "main.h"

#include "drivers/buttons.h"
#include "drivers/led.h"

#include "clock.h"
#include "state.h"
#include "drivers/display.h"
#include "edit.h"
#include "modules.h"
#include "utils/pins.h"
#include "utils/reg.h"
#include "services/sync.h"
#include "timers.h"
#include "night_mode.h"
#include "utils/utils.h"

#include "config.h"
#include "services/monitor.h"
#include "services/ldr.h"
#include "services/views.h"
#include "utils/ram.h"

using namespace Clock;

////////////////////////////////////
// Watchdog
////////////////////////////////////

// https://www.nongnu.org/avr-libc/user-manual/group__avr__watchdog.html
uint8_t _MCUSR __attribute__ ((section (".noinit")));

// .initN sections fall through — they are NEVER called, so naked is mandatory
// (a ret at the end would pop a garbage address and corrupt startup).
//
// IMPORTANT: The function body must be 100% pure inline asm with NO C code.
// Mixed naked+C is unreliable: avr-libc's wdt_disable() macro uses a "=d"
// output constraint that requires the compiler to allocate a scratch register,
// which without a prologue may be in an undefined state — the timed write
// sequence then silently fails and the WDT keeps firing every reset.
//
// This pure-asm version only uses r24 and r1 (__zero_reg__), which .init2
// guarantees to be available (r1=0, SP set up) by the time .init3 runs.
void get_mcusr(void) __attribute__((naked)) __attribute__((section(".init3")));
void get_mcusr(void)
{
    __asm__ __volatile__ (
        "in   r24, %[mcusr_io]\n\t"   /* r24 = MCUSR                        */
        "sts  _MCUSR, r24\n\t"        /* save to .noinit global             */
        "out  %[mcusr_io], r1\n\t"    /* MCUSR = 0  (clears WDRF)           */
        /* ATmega328P datasheet §11.8.2 timed WDT disable sequence:           */
        /* Step 1 — set WDCE+WDE simultaneously.                             */
        /* Step 2 — within the NEXT 4 cycles write 0 to WDE.                */
        "wdr\n\t"                      /* pet WDT before touching WDTCSR    */
        "ldi  r24, %[wdce_wde]\n\t"   /* r24 = WDCE|WDE (0x18)              */
        "sts  %[wdtcsr], r24\n\t"     /* WDTCSR = WDCE|WDE  ←timed start   */
        "sts  %[wdtcsr], r1\n\t"      /* WDTCSR = 0, WDE cleared ≤4 cycles */
        :
        : [mcusr_io]  "I" (_SFR_IO_ADDR(MCUSR)),
          [wdtcsr]    "n" (_SFR_MEM_ADDR(WDTCSR)),
          [wdce_wde]  "n" ((uint8_t)(_BV(WDCE) | _BV(WDE)))
        : "r24"
    );
}

////////////////////////////////////
// Resetovanie systemu
////////////////////////////////////

// uint16_t EEMEM reset_count_eeprom = 0;

// const char* resetReasonToString(uint8_t resetReason) {
//     if (resetReason & (1 << PORF))  return "POR: Power-on Reset";
//     if (resetReason & (1 << EXTRF)) return "EXT: External Reset (RESET pin)";
//     if (resetReason & (1 << BORF))  return "BOR: Brown-out Reset";
//     if (resetReason & (1 << WDRF))  return "WDT: Watchdog Reset";
//     return "Unknown";
// }

// void reportResetAndCount() {
//   uint16_t c = eeprom_read_word(&reset_count_eeprom);
//   c++;
//   eeprom_write_word(&reset_count_eeprom, c);
// }

////////////////////////////////////

/*
 * CASOVACE:
 *   Timer0 - 8 bit (millis, delay, micros)
 *      - piny 5, 6
 *
 *   Timer1 - 16 bit
 *      - piny 9, 10
 *
 *   Timer2 - 8 bit
 *      - piny 11, 3
 */

//  * CS02 CS01 CS00 Description
//  * 0     0     0   No clock source (Timer/Counter stopped)
//  * 0     0     1   clk I/O /(no prescaling) -> 16MHz / (1 * 256) = 62 500 Hz
//  * 0     1     0   clk I/O /8 (from prescaler) -> 16MHz / (8 * 256) = 7812.5 Hz
//  * 0     1     1   clk I/O /64 (from prescaler) -> 16MHz / (64 * 256) = 976.5625 Hz
//  * 1     0     0   clk I/O /256 (from prescaler) -> 16MHz / (256 * 256) = 244.140625 Hz
//  * 1     0     1   clk I/O /1024 (from prescaler) -> 16MHz / (1024 * 256) = 61.03515625 Hz
//  * 1     1     0   External clock source on T0 pin. Clock on falling edge.
//  * 1     1     1   External clock source on T0 pin. Clock on rising edge.
//  */

void loop() {
    if (State::isFlagSet(FLAG_NEW_SECOND)) {
        RAM::checkSafety(); // Kazdu sekundu overime, ze RAM este nevytiekla.

        // static uint8_t reset_held_seconds = 0;
        // if (IS_PRESSED(L_BTN)) {
        //     reset_held_seconds++;
        //     if (reset_held_seconds == 1) {
        //         sprintln(F("=== RAM STATUS ==="));
        //         sprint(F("Volna RAM:     ")); sprint(freeRam());            sprintln(F(" B"));
        //         sprint(F("Limit (reset): ")); sprint(RAM_SAFETY_THRESHOLD); sprintln(F(" B"));
        //         sprint(F("Canary:        ")); sprintln(stackCanaryIntact() ? F("OK") : F("CORRUPTED"));
        //         sprintln(F("=================="));
        //     } else if (reset_held_seconds >= 3) {
        //         sprintln(F("[TEST] Korupcia canary oblasti -> WDT reset..."));
        //         _stack_canary[0] = 0xDE;
        //         _stack_canary[1] = 0xAD;
        //         checkRamSafety(); // Okamzity WDT reset.
        //     }
        // } else {
        //     reset_held_seconds = 0;
        // }

        Edit::onSecondTick();
        Views::onSecondTick();

        Modules::updateConnectionStatus();

        #if INA_ENABLED
        if (Config::get(Config::CURRENT_SENSOR_ENABLED)) {
            Monitor::onSecondTick();
        }
        #endif

        #if DCF77_ENABLED
            DCF77Sync::onSecondTick();
        #endif

        static uint8_t last_hour = t_counter_hours; // inicializovane po setup()
        if (t_counter_hours != last_hour) {
            last_hour = t_counter_hours;
            Timers::onHourTick(t_counter_hours);
        }

        LDR::onSecondTick();

        State::clearFlag(FLAG_NEW_SECOND);
    }

    if (State::isFlagSet(FLAG_NEW_MILLIS)) {
        Buttons::onMillisecondTick();
        DCF77Sync::onMillisecondTick();

        if (Clock::State::inNightMode()) {
            NightMode::onMillisecondTick();
        }

        #if INA_ENABLED
            Monitor::onMillisecondTick();
        #endif

        State::clearFlag(FLAG_NEW_MILLIS);
    }

    #if WATCHDOG_ENABLED
        wdt_reset();
    #endif
}

void printSystemInfo() {
    sprintln(F("---------------------------------"));
    sprint(F("Voľná pamäť RAM:      "));
    sprint(RAM::free());
    sprintln(" bytes");
    sprint(F("RTC Modul (DS3231):       "));
    sprintln(Modules::isConnected(Modules::MODULE_DS3231) ? F("Pripojený") : F("Nepripojený"));
    sprint(F("Sensor prúdu (INA219):        "));
    sprintln(Modules::isConnected(Modules::MODULE_INA219) ? F("Pripojený") : F("Nepripojený"));
    sprintln(F("---------------------------------"));
}

void setup() {
    /****************************************
     * Indikacna LED-ka
     ****************************************/

    // Indikacnu LED-ku chceme mat zapnutu uz od zaciatku
    // aby mohla indikovat pripadne chyby pri starte.
    Led::setupRegisters();

    // Indikacia zapinania (LED-ka svieti na zlto).
    Led::setRGB(Led::Palette::STARTUP);

    /****************************************
     * Serial
     ****************************************/

    #if SERIAL_ENABLED
        // Serial pre debugovanie a logging
        Serial.begin(SERIAL_BANDWIDTH);

        sprintln(F("------------------------------------"));
        sprintln(F("Spúšťanie hodín..."));
    #endif

    /****************************************
     * Nepouzite piny a periferie
     ****************************************/

    // SPI (MISO, MOSI, SCK) pouzivame len pri programovani.
    SPCR &= ~(1<<SPE);  // vypneme vsetky SPI periferie
    PRR  |= (1<<PRSPI);  // fyzicky vypneme SPI

    // Vypneme externe interupty.
    EIMSK &= ~((1<<INT0)|(1<<INT1));
    EIFR  |=  (1<<INTF0)|(1<<INTF1);

    // Toto riesime na zaciatku, ak by nahodou nejake z tychto pinov predsa
    // len niekedy neskor pouzite boli.
    sprintln(F("Definovanie pevných logických hodnôt pre nepoužité piny..."));

    // Kvoli bezpecnosti, nepouzite piny definujeme explicitne.
    // Je lepsie ak nejaky pin ostane vo vzduchu ako by sme mali nieco poskodit.
    // !! Treba sa uistit, ze na tychto pinoch naozaj nie je nic pripojene.
    UNUSED_PIN(C, PC2);
    UNUSED_PIN(D, PD6);

    // PC6 - Pouzivame ako RESET

    #if !SERIAL_ENABLED
        // tieto piny sa pouzivaju len ak je serial zapnuty.
        UNUSED_PIN(D, PD0); // Serial RX
        UNUSED_PIN(D, PD1); // Serial TX

        UCSR0B &= ~((1<<TXEN0) | (1<<RXEN0));  // Vypneme tx/rx
        PRR |= (1 << PRUSART0); // Vypneme USART zbernicu.
    #endif

    // Tento pin sme sa rozhodli nepouzit, ale kedze je na nom trimmer
    // ktory funguje ako 0-50K pullup musime sa uistit, ze ak bude trimmer
    // nastaveny na 0, nedojde k skratu, takze tento pin nikdy nemoze bit v stave OUTPUT LOW!
    CBI(DDRC,   LED_BRIGHTNESS_TRIM); SBI(PORTC,  LED_BRIGHTNESS_TRIM);

    /****************************************
     * Zbernica registrov.
     ****************************************/

    #if DISPLAY_ENABLED
        sprintln(F("Konfigurácia zbernice registrov pre displej..."));

        CBI(PORTB,  SRCK_PORTB);    SBI(DDRB,   SRCK_PORTB);
        CBI(PORTD,  RCK_PORTD);     SBI(DDRD,   RCK_PORTD);
        CBI(PORTB,  SERIN_PORTB);   SBI(DDRB,   SERIN_PORTB);
        // Musime pouzit OUTPUT rezim pretoze je tam externy 10K pullup (potrebujeme silnu hodnotu).
        SBI(PORTD,  _G_PORTD);      SBI(DDRD,   _G_PORTD);
    #endif

    /****************************************
     * PWM Jas
     ****************************************/

    #if DISPLAY_ENABLED
        sprintln(F("Konfigurácia PWM kanálu pre jas..."));

        STOP_DISPLAY_PWM();

        OCR0A = DISPLAY_PWM_TOP;
        OCR0B = 0;

        TIMSK0 = 0; // Vypneme prerusenie tohto casovaca.
    #endif

    /****************************************
     * Nastavenie pinov DCF77 modulu
     ****************************************/

    #if DCF77_ENABLED
        sprintln(F("Konfigurácia pinov DCF77 prijímača..."));

        CBI(DDRC, DCF_OUT);
        CBI(PORTC, DCF_OUT);

        CBI(DDRB, DCF_PON);
        // V hardveri by mala byt dioda ktora zabrani pripadnemu poskodeniu.
        CBI(PORTB, DCF_PON); // POZOR! 3V3 logika
    #endif

    /****************************************
     * IO Piny
     ****************************************/

    sprintln(F("Inicializácia vstupno-výstupných pinov..."));

    CBI(DDRD,   L_BTN); SBI(PORTD, L_BTN); // INPUT PULLUP (620R v serii)
    CBI(DDRD,   R_BTN); SBI(PORTD, R_BTN); // INPUT PULLUP (620R v serii)

    #if DISPLAY_ENABLED
        // Zapneme slabych 5 V ktore su tahane dole cez LDR rezistor.
        CBI(DDRC,   LDR_PIN_PORTC); SBI(PORTC, LDR_PIN_PORTC); // INPUT PULLUP
    #else
        UNUSED_PIN(C, LDR_PIN_PORTC);
    #endif

    CBI(DDRD,   RESET_BUTTON);  SBI(PORTD,  RESET_BUTTON); // INPUT PULLUP (620R)

    /****************************************
     * Analogovy vstup
     ****************************************/

    #if ADC_ENABLED
        // Spolocne pre NORMAL_ADC_MODE aj pre COMPARATOR_ADC_MODE
        ADMUX = (ADMUX & 0xF0) | (DCF_OUT & 0x07);
        ADCSRA = (1 << ADPS2) | (1 << ADPS1) | (1 << ADPS0);  // /128 prescaler
        ACSR = (1 << ACBG);
    #endif

    /****************************************
     * Hlavny Casovac (1kHz)
     ****************************************/

    sprintln(F("Konfigurácia časovača..."));

    // WGM21 -> CTC rezim, zresetuje citac po dosiahnuti limitu
    TCCR2A = (1 << WGM21);

    // CS22 -> Delic 64
    TCCR2B = (1 << CS22);

    // Fcas = 16MHz / (64 x 250) = 1kHz
    OCR2A = 249; // nastavime limit casovaca
    TCNT2 = 0; // Zaciname pocitat od nuly.

    // Zapne interupt, ktory sa vykona pri dosiahnuti limitu (TIMER2_COMPA_vect)
    TIMSK2 = (1 << OCIE2A);

    sprintln(F("Spúšťanie prerušení..."));
    INTERRUPTS_ON; // Od tohto bodu funguje ISR-ko, takze hodiny uz "tikaju"...

    /****************************************
     * Bootovanie Displeja
     ****************************************/

    // Displej rozsvietime ihned po starte preruseni, este pred I2C/EEPROM init.
    // Pocas diagnostiky prebehne vsetka pomala inicializacia (I2C, RTC, INA, EEPROM)
    // a uzivatel vidi vsetky segmenty po celu dobu bootu.
    #if DISPLAY_ENABLED
        sprintln(F("Zapínanie displeja..."));
        Display::boot();
    #endif

    /****************************************
     * Moduly
     ****************************************/

    // Nechame moduly spustit, to zaberie nejaky cas.
    sprintln(F("Inicializácia modulov..."));
    Modules::initializeModules();

    // Vzdy pockame.
    Utils::wait(BOOT_DIAG_MIN_MS);

    #if DISPLAY_ENABLED
        sprintln(F("Úvodná diagnostika dokončená."));
    #endif

    /****************************************
     * RESET Tlacitko
     ****************************************/
    // ! Restujeme az po casovom obmedzeni,
    // ! aby sme predisli nechcenym resetom.

    // Ak je tlacidlo RESET stlacene pri starte (po RESETovani cipu)
    // tak nenacitame ulozene konfiguracie -> pouziju sa vychodzie hodnoty.
    // Zaroven zresetujeme cas ulozeny v RTC module.
    if (IS_PRESSED(RESET_BUTTON)) {
        sprintln(F("RESET tlačidlo bolo stlačené, použijeme východzie "
                    "hodnoty nastavení."));

        // Ulozime vsetky konfiguracie do EEPROM este pred ich nacitanim z EEPROM,
        // takze pouzijeme vychodzie hodnoty.
        Config::saveAll();

        // Trikrat zablikame ledku, na znak uspesneho resetu.
        for (uint8_t i = 0; i < 3; i++) {
            // SBI(PORTB, Led::Color::RED); SBI(PORTB, Led::Color::GREEN); SBI(PORTB, Led::Color::BLUE);
            Led::setRGB(Led::Palette::FACTORY_RESET);
            Utils::wait(300);
            Led::setRGB(0, 0, 0);
            // CBI(PORTB, Led::Color::RED); CBI(PORTB, Led::Color::GREEN); CBI(PORTB, Led::Color::BLUE);
            Utils::wait(300);
        }

        #if RTC_ENABLED
        sprintln(F("Resetovanie casu a datumu na predvolene hodnoty."));
        // Zresetujeme cas v RTC module na predvolene hodnoty nastavenia casu.
        Modules::DS3231::DateTime dt{
            /*second=*/ 0,
            /*minute=*/ (uint8_t)(Config::get(Config::TIME_M10) * 10u + Config::get(Config::TIME_M1)),
            /*hour=*/   (uint8_t)(Config::get(Config::TIME_H10) * 10u + Config::get(Config::TIME_H1)),
            /*day=*/    (uint8_t)(Config::get(Config::DATE_DAY_D10) * 10u + Config::get(Config::DATE_DAY_D1)),
            /*month=*/  (uint8_t)(Config::get(Config::DATE_MONTH_D10) * 10u + Config::get(Config::DATE_MONTH_D1)),
            /*year=*/   (uint16_t)(Config::get(Config::YEAR_D1000) * 1000u + Config::get(Config::YEAR_D100) * 100u
                                 + Config::get(Config::YEAR_D10)  *   10u  + Config::get(Config::YEAR_D1))
        };
        Modules::DS3231::adjust(dt);
        #endif

        sprintln(F("Resetovanie kalibračných údajov senzoru prúdu."));
        Monitor::clearCalibrationTable();
    } else {
        sprintln(F("Načítavanie uložených konfigurácií z EEPROM..."));
    }

    /****************************************
     * Nastavenia a kalibracia
     ****************************************/

    // ! Musi byt volane az po obsluhe RESET tlacidla, aby sme mali predvolene hodnoty po ruke.
    Edit::setupAllConfigurations();

    // ! Musime zabezpecit, ze monitorovanie je defaultne vypnute, aby v pripade, ze
    // ! sa tento volitelny system rozbije, sme ho mohli vypnutpodrzanim tlacidla RESET.
    if (Config::get(Config::CURRENT_SENSOR_ENABLED)) {
        if (!Monitor::loadCalibrationTableFromEEPROM()) {
            sprintln("Nepodarilo sa nacitat kalibracnu tabulku pre Monitor s "
                     "EEPROM.");
            sprintln("Spustame automaticku kalibraciu.");

            // V pripade, ze chceme kalibraciu opakovat, najprv vypneme monitorovanie
            // odberu displeja v nastaveniach, to vymaze celu kalibracnu tabulku z pamate.
            // Nasledne ju opat zapneme a restartujeme hodiny (staci cez tlacidlo RESET).
            Monitor::runCalibration();
        }
    }

    sprintln(F("Zobrazovanie času..."));
    updateTimeCountersFromTimeSources(); // Uistime sa, ze mame pocitadla aktualne.
    Display::displayTimeFromCounters(t_counter_minutes, t_counter_hours);

    Led::setRGB(0, 0, 0); // Vypneme indikacnu LED-ku signalizujucu spustanie.

#if DCF77_ENABLED
    if (Config::get(Config::DCF77_SYNC_ENABLED)) {
        sprintln(F("Spúšťanie DCF77 prijímača..."));
        // Pri zapnuti hned zahajime synchronizaciu.
        // Neviem totiz, ako dlho sme boli vypnuti.
        DCF77Sync::startSynchronization();
        sprintln(F("DCF77 prijímač inicializovaný."));
    }
#endif

    printSystemInfo();


    sprintln(F("Spúšťanie hodín dokončené!"));

    Led::setRGB(0, 9, 9);
    Led::lock();
}

int main(void) {
    // Zaloha: ak .init3 pure-asm sekvencia z nejakeho dovodu nezafungovala
    // (napr. iny prekladac, ine optimalizacie), disablujeme WDT este raz tu,
    // skor ako cokolvek ine stihne prebehnut. C-runtime uz bezi korektne,
    // takze avr-libc wdt_disable() funguje spolahlivo.
    MCUSR = 0;
    wdt_disable();

    // Pocas setupu su interupty vypnute.
    INTERRUPTS_OFF;

    // Ihned oznacime canary oblast aby sme mohli neskor detekovat pretecenie zasobniku.
    RAM::initCanary();

    // I2C pull-upy - Wire ich nastavi sam cez Wire.begin(),
    // ale explicitne ich nastavime tu pre istotu
    PORTC |= (1 << PC4) | (1 << PC5);
    DDRC &= ~((1 << PC4) | (1 << PC5)); // vstup

    setup();

    // Inicializacia hodin prebehla uspesne, zapneme watchdog.
#if WATCHDOG_ENABLED
    // Zapneme watchdog, ak sa 8 sekund nezresetuje, zresetuje hodiny.
    wdt_enable(WDTO_8S);
    wdt_reset();
#endif

    for (;;) {
        wdt_reset();
        loop();
    }

    // Sem sa nikdy nedostaneme, ale potlacime warning
    return 0;
}

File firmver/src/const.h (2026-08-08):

/*
 * const.h
 *
 *  Vseobecne konstanty hodin, ktore pouzivame v roznych suboroch.
 */

#ifndef CONST_H
#define CONST_H

#include <util/atomic.h>

#define NO_INTERRUPTS_SECTION   ATOMIC_BLOCK(ATOMIC_RESTORESTATE)
#define INTERRUPTS_OFF          cli()
#define INTERRUPTS_ON           sei()

#define DEBUG_MODE       1

// Debug helper: force enter night mode right after boot sequence.
// Set to 0 after validation.
#define NIGHT_MODE_SIM_ON_BOOT 1

#define DIGIT_COUNT      4

#define ON  1
#define OFF 0

#define PRESSED  0
#define RELEASED 1

#define SUPPLY_VOLTAGE          (5)

// Serial moze robit bordel ak programujeme cez UART zbernicu.
#define SERIAL_ENABLED   1
#define RTC_ENABLED      1
#define INA_ENABLED      1
#define DISPLAY_ENABLED  1

#define DCF77_ENABLED    0
#define CRSF_ENABLED     DISPLAY_ENABLED // !
#define LDR_ENABLED      1
// wdt_reset() v Serial::write() a timeout v waitUntil() resia kompatibilitu.
#define WATCHDOG_ENABLED 1

#define I2C_ENABLED (INA_ENABLED || RTC_ENABLED)
#define ADC_ENABLED (LDR_ENABLED || DCF77_ENABLED)

// Flagy (indexi bitov)
#define FLAG_NEW_SECOND    0
#define FLAG_NEW_MINUTE    1
#define FLAG_NEW_MILLIS    2
#define FLAG_DCF_LEDONN    3
#define FLAG_DCF_SYNC      4

#define SECOND_MILLIS     1000
#define MINUTE_MILLIS     60000
#define MAX_MINUTES_COUNT 60
#define MAX_HOURS_COUNT   24
#define MAX_HOURS_TENS    2

#define CALLED_FROM_ISR
#define ONLY_IN_ISR

#endif // CONST_H

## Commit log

2025-05-28 migrácia na github
    [iv-9 v1.step, numeri-iv9-hodiny.kicad_pcb, numeri-iv9-hodiny.kicad_sch]
2025-06-02 Pridaný kód firmwaru + úpravy schéma a DPS s anglickým prekladom.
    [external-iv9-socket.kicad_pcb, external-iv9-socket.kicad_sch, external-iv9-socket.step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]
2025-06-06 Veľké pokroky pri navrhu DPS.
    [external-iv9-socket.kicad_pcb, external-iv9-socket.kicad_sch, external-iv9-socket.step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]
2025-06-18 Pomerne velke zmeny a prehodnotenia zakladnych veci.
    [BH-642.STEP, Battery Holder Top with CR2032.stp, em2s-hkw-module.kicad_pcb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]
2025-06-27 Zase po dlhej dobe nejaký zálohovací commit.
    [HW-84 v7 v2.step, HW-84 v7.step, external-iv9-socket v13 v6.step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]
2025-07-12 Pridaný 3D model ktorý údajne pôjde zobraziť v Githube.
    [dcf77_antena_10x140mm.step, drziak_ledky.step, fuse-holder-5x20mm.STEP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]
2025-07-13 preventívne
    [numeri-iv9-hodiny-atmega328.kicad_pcb, numeri-iv9-hodiny-atmega328.kicad_sch, pin header 1x3 and jumper.step]
2025-07-16 Pridaná bloková schéma.
    [blokova_schema.kicad_sch, numeri-iv9-hodiny-atmega328.kicad_pcb, numeri-iv9-hodiny-atmega328.kicad_sch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]
2025-07-25 Prvá iterácia.
    [external-iv9-socket.kicad_pcb, numeri-iv9-hodiny-atmega328.kicad_pcb, numeri-iv9-hodiny-atmega328.kicad_sch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]
2025-07-25 Príručka v PDF formáte.
    [numeri-iv9-hodiny-atmega328.kicad_pcb]
2025-08-05 Zase po dlhšej dobe preventívny commit.
    [Standoff mf - M4 x 20 across flats 7mm.step, Standoff_M3_14mm.step, external-iv9-socket.kicad_pcb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]
2025-08-07 Aktualizovaný manuál a nejaké menšie zmeny.
    [numeri-iv9-hodiny-atmega328.kicad_pcb, numeri-iv9-hodiny-atmega328.kicad_sch, numeri-iv9-hodiny.kicad_pcb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]
2025-08-10 Záloha pred druhým tlačením.
    [numeri-iv9-hodiny-atmega328-rev2.kicad_pcb, numeri-iv9-hodiny-atmega328.kicad_pcb, numeri-iv9-hodiny-atmega328.kicad_sch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]
2025-08-12 Úpravy stránky a firmvéru.
    [export.kicad_pcb, numeri-iv9-hodiny-atmega328.kicad_pcb, numeri-iv9-hodiny-atmega328.kicad_sch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]
2025-08-19 Pridaný firmware.
    [external-iv9-socket.kicad_pcb, numeri-iv9-hodiny-atmega328.kicad_sch, schema.kicad_sch]
2025-08-19 Úpravy firmvéru.
    [numeri-iv9-hodiny-atmega328.kicad_pcb]
2025-08-22 Preventívne nahratie.
    [export.kicad_pcb, numeri-iv9-hodiny-atmega328.kicad_sch, schema.kicad_sch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]
2025-08-24 Nove fotky.
    [numeri-iv9-hodiny-atmega328.kicad_sch, schema.kicad_sch]
2025-08-31 Nahratý nový firmvér.
    [__schema.kicad_sch, dcf77_antena_10x60mm.step, iv9.kicad_sch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]
2025-09-08 Nové fotky a úpravy stránky.
    [Stojan na hodinky v2.obj, Stojan na hodinky v2.stl, export.kicad_pcb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]
2025-10-15 Mierne úpravy schémy, dopísanie niektorých častí príručky a pomerne rozsiahle opravy a optimalizácie firmvéru.
    [numeri-iv9-hodiny-atmega328.kicad_sch, schema.kicad_sch]
2025-11-09 Preventívne uloženie na github.
    [numeri-iv9-hodiny-atmega328.kicad_sch, schema.kicad_sch]
2025-12-12 Opravy v schéme. Úpravy a optimalizácie firmvéru.
    [export.kicad_pcb, numeri-iv9-hodiny-atmega328.kicad_pcb, schema.kicad_sch]
2026-02-25 Dalsie masivne zmeny. Pridané casovace, aj ked zatial este moc nefunguju.
    [__numeri-iv9-hodiny-atmega328.kicad_pcb, export.kicad_pcb, numeri-iv9-hodiny-atmega328.kicad_pcb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]
2026-03-23 Pridaný led driver pre RGB ledku.
2026-05-05 Upravený návrh dosky.
    [numeri-iv9-hodiny-atmega328.kicad_pcb, schema.kicad_sch]
2026-05-19 Pravdepodobne posledná verzia príručky + drobné úpravy firmvéru.
    [numeri-iv9-hodiny-atmega328.kicad_pcb, stojan na anténu.f3d]
2026-05-21 Vytlacena verzia prirucky + novy model, zatial v stadiu testovania.
    [Standoff mf - M4 x 20 across flats 7mm.step, Standoff_M3_14mm.step, Stojan na hodinky v2.obj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]
2026-05-21 Optimalizovane a aktualizovane modely.
    [clock-pcb.blend, clock-with-antenna.blend]
2026-05-27 Aktualizácia fotiek a stránky.
    [clock-pcb.blend, clock-with-antenna.blend]
2026-06-08 - Opravene ukladanie casu aj ked nebol meneny. - Opravena chyba pri ktorej sa nezosynchronizovali sekundy pri DCF77 synchronizácií. - Opraveny systém zámkou pre LED. - Signalizácia nespravne nastaven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
